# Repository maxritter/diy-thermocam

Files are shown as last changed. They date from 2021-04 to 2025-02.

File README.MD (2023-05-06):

# DIY-Thermocam



The DIY-Thermocam V3 is an open-source thermal imager based on the FLIR Lepton LWIR sensor.

Check out the official website for more information about the project: **[www.diy-thermocam.net](https://www.diy-thermocam.net/)**

**This repository contains:**

- **[Latest firmware releases](https://github.com/maxritter/diy-thermocam/releases)**
- **[Open-source firmware](https://github.com/maxritter/diy-thermocam/tree/master/firmware)**
- **[Desktop software](https://github.com/maxritter/diy-thermocam/tree/master/software)** 
- **[Device enclosure](https://github.com/maxritter/diy-thermocam/tree/master/enclosure)**
- **[Printed circuit board](https://github.com/maxritter/diy-thermocam/tree/master/pcb)**



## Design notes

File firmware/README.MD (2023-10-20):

# DIY-Thermocam - Firmware

### THIS GUIDE IS ONLY REQUIRED, IF YOU WANT TO MAKE CHANGES TO THE FIRMWARE ON YOUR OWN

In case you want to flash the newest version of the firmware to your device without modification, **go to the release section of this repo**.

This guide should work on **all common operating systems** (**Windows, Linux & macOS**).

You need to have [VS Code](https://code.visualstudio.com/) with the [PlatformIO extension](https://platformio.org/install/ide?install=vscode) installed and download the zip archive of this repository. Then **unpack the 3.0 folder inside the firmware subfolder**, **start VS Code** and open this folder  with **File -> Open Folder**. 

**PlatformIO should initialize itself automatically** and you see the buttons to **Build, Upload and Clean** the project in the blue bar **at the bottom**. If this is not the case, **set it up manually using the instructions provided [here](https://platformio.org/install/ide?install=vscode)**.

**Before you click "Upload"**, make sure the Thermocam is **connected to the PC** via a micro USB cable and **turned on**. The **Teensy CLI** should then automatically detect it and **flash the .hex file to the board**. After a restart the changes should be present on the device.

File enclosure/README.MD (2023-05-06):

# DIY-Thermocam - Enclosure

The enclosure has been designed with Google Sketchup in 3D and converted to 2D files to laser-cut them. The 2D SVG file can be opened with Inkscape.

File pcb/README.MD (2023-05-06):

# DIY-Thermocam - PCB

## General

The printed circuit board has been created with [Autosoft Eagle](http://www.autodesk.com/education/free-software/eagle).
Use this software to open the [schematic](3.0/pcb.sch) or [board](3.0/pcb.brd) file.

You can also use the [Gerber.zip](3.0/gerber.zip) and upload it to any PCB service of your choice to manufacture the board, for example [Smart Prototyping](http://www.smart-prototyping.com/PCB-Prototyping.html). 

The PCB dimensions are 89.4mm (w) x 68.4mm (h), 1.6mm thickness and 2 layers.

## Front

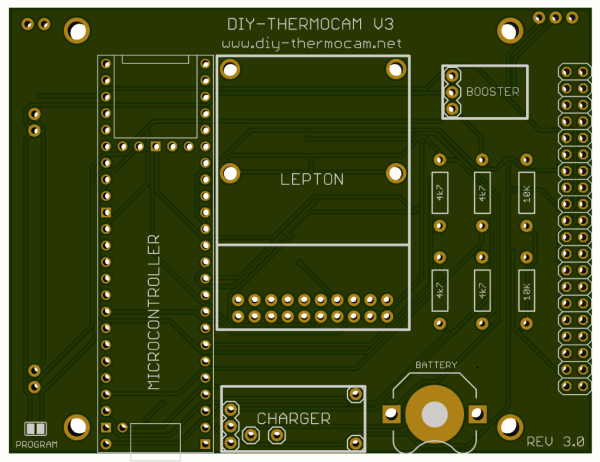
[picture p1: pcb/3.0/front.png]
Front


## Back

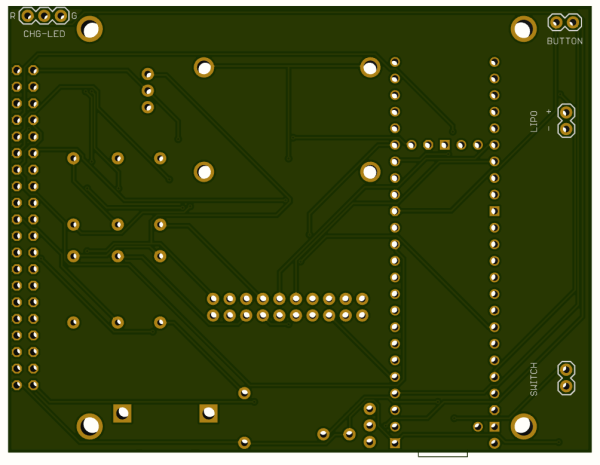
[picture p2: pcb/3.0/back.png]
FRONT


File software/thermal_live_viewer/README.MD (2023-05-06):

# DIY-Thermocam - Thermal Live Viewer

This Python application allows you to connect to your DIY-Thermocam from a PC over the USB serial protocol and stream live thermal images. Run the main.py and change the comport for the device to work.

The Video Recording relies on FFMPEG and does currently only work under Windows.

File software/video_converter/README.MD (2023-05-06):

# DIY-Thermocam - Video Converter

This video converter allows you to convert a whole folder containing bitmap frames from a video or timelapse capture into a movie file.

You can either convert the raw data files to bitmaps on the device, or use the thermal data viewer together with the batch export function to do so (faster).

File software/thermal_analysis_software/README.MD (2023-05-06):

# DIY-Thermocam - Thermal Analysis Software

The thermal analysis software called ThermoVision is created by Joe-C.  The latest stable version that works well with the DIY-Thermocam is 1.7.0.0.

Use the Sample.DAT file in this folder to try out the functionalities of the software. Just drag it into the Main IR window to load it.

For more information and the changelog, check out the [authors website](https://translate.google.com/translate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).

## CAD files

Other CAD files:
enclosure/3.0/enclosure.skp

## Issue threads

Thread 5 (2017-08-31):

choice of microcontroller

haraldg, 2017-08-31:
Hi,

this is a great project and I'm very likely to build a DIY-Thermocam myself.

However, I find it somewhat unfortunate, that the design is based around the TEENSY 3.6 instead of the
[iMX233-OLinuXino-NANO](https://www.olimex.com/Products/OLinuXino/iMX233/iMX233-OLinuXino-NANO/open-source-hardware) which is cheaper, OSHW, industrial grade and already has many of the features on the board that DIY-Thermocam needs extra components for. Though admittedly getting things like the on board battery charger to work might require a non-trivial effort.

Anyway this issue is an attempt to find like-minded people who might join forces to adapt the design to the OLinuXino-NANO or solicit input on why this would be a bad idea.

maxritter, 2017-09-12:
The mentioned single board controller from Olimex is using Linux, whereas the Teensy 3.6 is a bare metal microcontroller. Of course you could also implement the Thermocam on a board running an operating system, like the Raspberry Pi Zero for example, but I decided to implement this project in bare metal C++ on an ARM Cortex M board.

haraldg, 2017-09-14:
The imx233 controller can definitely be programmed in bare metal C++, though maybe some libraries available for the Teensy might be missing. However having a full operating system available is actually the second reason why a Thermocam based on an olinuxino board would appeal to me.

I'm waiting for my order to arraive. After assembling and testing my own Thermocam I will decide how much effort I'm willing to put into a redesign. Of course any input anymone might have is still greatly appreciated.

haraldg, 2017-09-23:
As I'm still looking for people interested in porting the DIY-Thermocam to a OSHW single board computer, I'd appreciate if this issue could remain open to give it some visibility. Is there any reason to close it?

Nprod, 2019-02-01:
It's probably not what you have in mind, but it is possible to use just the FLIR Lepton breakout board directly on any Raspberry pi using the GPIO pins. If the olinuxino, or any other single-board computer of choice has I2C and SPI pins in its GPIO board, you should be able to get a Lepton running. I've successfully gotten it to run on a chinese Orange PI, the main downside being that it's running a full operating system so the whole setup isn't portable.

Max's diy-thermocam is more expensive and more complicated to setup by comparison, but it has one big advantage that it's all integrated into a single unit. And when you're taking thermal images chances are you'll be out and about.

maxritter, 2019-02-01:
That's true :) There are various other projects and tutorial using a more advanced SOPC like the Raspberry for directly controlling and displaying the thermal image from the Lepton.

I think as you said, it depends on your use case and of course also the budget.

haraldg, 2019-02-02:
Yes. However I specifically suggested the olinuxino, because I believe such a setup would be as portable and the PCB interfacing the main board and the lepton would be almost trivial. (Ie making it easier to optimize for themal constraints, etc.)

The big part of such a project would be writing the firmware (probably mostly from scratch) as a linux application. My current estimate is, that developing a ThermocamV3 based on the olinuxino or other SBC would take me about 1-2 month full time work. - For something, that works. Doing it properly, ie. submitting drivers upstream to the mainline kernel, etc. would take even longer.

Unfortunately I don't have that much free time these days. Also the ThermocamV2 works too well for me, to put that much effort into something that would be slightly cheaper, a bit more flexible and OSHW.

However if somebody else is taking the initiative, I'd still be happy to help out with my skills. (Mostly kernel and embedded linux related.)

Nprod, 2019-02-02:
I don't know, sounds like a lot of work for something that's just 4€ cheaper. Maybe the added CPU power would make the image refresh rate quicker, but that's already limited to 9hz in the lepton itself...

Closed 2021-03-10.

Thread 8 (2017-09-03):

Calibrating problems

alexandreamato, 2017-09-03:
Hi,
I just built my own DIY-Thermocam. Congratulations on the project! If I were more careful I would have taken some photos of the built process to share with you and here. I really like the [thermography and made some attempts before](https://www.youtube.com/watch?v=XctIPPcHPTE&feature=youtu.be).
Anyway. I know it is working, at least a part of it, because I can start the calibration process, and I can move the arrows to put thermo image over photo image. But after that, calibrations asks to point to different heat objects slowly, but my calibration process never changes, stays at 0%.
Also, I had to upload firmware version 2.40. I don't know why when uploading newer versions it says my teensy is not compatible.
One hint for everyone, I use Windows 10, and there was no way to upload firmware in COM10, but it was very easy with https://github.com/Koromix/tytools
Do anyone have any idea how to pass or bypass this calibration?
Thanks

nielsswinkels, 2017-09-04:
Did you see the Firmware update manual? In there at step 5 there is a link to how to change the comport on windows to com 10: http://plugable.com/2011/07/04/how-to-change-the-com-port-for-a-usb-serial-adapter-on-windows-7/

nielsswinkels, 2017-09-04:
Which teensy are you using?
And are you using the firmware updater?

alexandreamato, 2017-09-08:
I believe it is a 3.6 Teensy, my order says: 1568-1442-ND 32.50000 32.50, TEENSY 3.6, HTSUS: 8471.50.0150 ECCN: 3A991A2, LEAD: LEAD NA ROHS: ROHS NA, COUNTRY/ORIGIN: USA
I didn't use the firmware updater because tytools managed to update at least the 2.40 version without changing to COM10. Do you believe it is necessary? I will do it tomorrow!
Also, regarding calibration, can you imagine why I cannot progress? it stays in 0%?
I only had problems soldering the 2 smallest pins in the SD card, they were very difficult. But I believe they are not the most important ones?! Or am I wrong?

alexandreamato, 2017-09-09:
I did it, using the upgrade app and the com10 port I managed to upgrade to the latest firmware.
My only problem now is calibrating. It stays calibrating forever.
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

nielsswinkels, 2017-09-09:
I have to admit i don't know much, except that i recently put together one of these.

I wonder if it could be an issue with the big cylindrical sensor? If i understand it correctly that is used to know actual temperature values from the values the heatcamera sensor says. Could you double check that is mounted correctly?

As for your photo, i can't see if the solder point is ok, it is to blurry for me. But you could always try to resolder it if you don't trust it?

alexandreamato, 2017-09-12:
I rechecked the big cylindrical sensor, it is positioned correctedly and soldered ok. Is it very fragile? Can it be broken? Do you have any idea how to test it?
Resoldering the location of the photo would be very difficult because of the location. But it is the SD card, so I studied the code, to see what happened when it stopped working. It doesn't yet access the SD card, so it is not the problem.
It seems it stops here:

`//If the temperature changes too much, do not take that measurement
//Get 100 different calibration samples
		while (counter < 100) {
			//Store time elapsed
			long timeElapsed = millis();

			//Repeat measurement as long as there is no new average
			do {
				//Safe delay for bad PCB routing
				delay(10);
				//Get temperatures
				lepton_getRawValues();
				//Calculate the average
				average = calcAverage();
			} while ((average == average_old) || (average == 0));

			//Store old average
			average_old = average;

			//Measure new value from MLX90614
			temp = mlx90614_getTemp();

			//If the temperature changes too much, do not take that measurement
if (abs(temp - temp_old) < 10) {
				//Store values
				calLepton[counter] = average;
				calMLX90614[counter] = temp;

				//Find minimum and maximum value
				if (average > maxValue)
					maxValue = average;
				if (average < minValue)
					minValue = average;

				//Refresh status on screen in steps of 10, not for serial
				if (((counter % 10) == 0) && !serial) {
					char buffer[20];
					sprintf(buffer, "Status: %2d%%", counter);
// It arrives here at least once
					display_print(buffer, CENTER, 140);
				}

				//When doing this in serial mode, print counter
				if (serial)
					Serial.write(counter);

				//Raise counter
				counter++;
			}

			//Store old spot temperature
			temp_old = temp;

			//Wait at least 111ms between two measurements (9Hz)
			while ((millis() - timeElapsed) < 111);

			//If the user wants to abort and is not in first start or serial mode
			if (touch_touched() && !firstStart && !serial) {
				int pressedButton = buttons_checkButtons(true);
				//Abort
				if (pressedButton == 0)
					return;
			}
`
As "Status" remains at 0%, I imagine something is happening in this loop. I wanted to try the serial output, but the "FirstStart" routine runs the "calibrationProcess" with serial as false. I am really lost here.

maxritter, 2017-09-12:
Hey there,

sorry for my late reply, I was on vacation.

As the combined alignment screen is working, the FLIR Lepton sensor and visual camera are doing fine. The calibration screen utilizes the MLX90614 spot sensor for the first time.

Two things can go wrong here:
- You use the wrong version of the MLX90614. Only the BCF version is supported for the DIY-Thermocam V2
- You soldered the sensor in the wrong position. Check step 10 of the assembly guide and make sure the little indicator matches the mark on the PCB

Also check if there is a 3.3V voltage between VCC and GND of the MLX90614 and that SDA is connected to Teensy pin 18 and SCL to Teensy pin 19, with no connections to other pins. The datasheet contains the pin locations: https://github.com/maxritter/DIY-Thermocam/blob/master/Datasheets/MLX90614.pdf

Please tell me if that solved your problem.

Wishes,
Max

alexandreamato, 2017-09-12:
Hi Max, it is an honor to talk to you. Congratulations on your project. It is very interesting!!
I tried all the suggestions:
I believe the version is right, I bought it directly from the link in github, If starts with BCF, but the number following is 9696A. I attached a photo
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
The position is right:
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
Voltage OK
pin 18 and pin 19 seems ok. But I noticed is connected to other pins by the board.
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
the only piece I had to substitute was a missing 4.7k resistor that didn't came in the kit. I used a bigger one, but with the same resistance.

maxritter, 2017-09-13:
Thank you very much for your compliment :)

From the pictures, everything looks solid! The spot sensor is also the right version.

So for the hardware side, I can only recommend you to resolder all pins and check if there are no hidden solder bridges, sometimes they are very small. Also check that the Lepton sensor is inserted tightly into the socket.

For the software side, you can try to reset the EEPROM so the spot sensor is flashed once again. Upload this sketch with the Teensy Loader, then reflash firmware 2.43: https://www.dropbox.com/s/jqcwolz5vajj0u5/eeprom_clear.ino.hex?dl=1

When in calibration mode, you have to move the device around to different temperatures, otherwise it will not make any progress. But a moving hand in front of the sensor should be enough to let it progress.

In case all that does not help, you can try to skip the calibration and directly proceed to live mode. Flash this sketch, I commented out the calibration part here: https://www.dropbox.com/s/jtglat0sg5msu17/NoCalibration.hex?dl=1
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
alexandreamato, 2017-09-13:
I need to go back to my lab to do that. Probably later today! Thanks

alexandreamato, 2017-09-14:
Here is the output:
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

maxritter, 2017-09-15:
Okay, so it got stuck in a while loop..

Please try that firmware file: https://www.dropbox.com/s/e6encj2gxblkum0/Firmware_V2_FixCalib.hex?dl=1

alexandreamato, 2017-09-16:
here it is. "Bad Calibration", but doesn't halt
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

maxritter, 2017-09-18:
Alright, so let's see what temperatures and raw values the device measures during calibration..

Please flash this file: https://www.dropbox.com/s/zqa7e7krh5r6io8/Firmware_V2_CalibOut.hex?dl=1

And send me the debug output as .txt / .csv file.
It prints three lines for each of the 100 measurements. First is id, second Lepton raw value and third MLX90614 absolute temperature. Either the raw value or abs. temp. must be wrong.

alexandreamato, 2017-09-21:
Hi, I had some trouble to upload the new firmware, but here it is:

7723
26.34
93
7723
26.14
94
7723
26.36
95
7723
26.36
96
7723
26.34
97
7723
26.34
98
7723
26.10
99
7723
26.36

alexandreamato, 2017-09-22:
a full one:

0
8149
36.88
1
8149
36.64
2
8149
36.76
3
8149
36.78
4
8149
36.36
5
8149
36.86
6
8149
36.94
7
8149
36.78
8
8149
36.60
9
8149
37.12
10
8149
37.12
11
8149
36.94
12
8149
36.94
13
8149
35.58
14
8149
37.60
15
8149
37.34
16
8149
37.24
17
8149
37.28
18
8149
37.60
19
8149
37.26
20
8149
37.26
21
8149
36.94
22
8149
36.94
23
8149
36.94
24
8149
36.60
25
8149
36.60
26
8149
37.02
27
8149
36.60
28
8149
36.62
29
8149
36.80
30
8149
36.84
31
8149
37.08
32
8149
36.72
33
8149
36.72
34
8149
36.60
35
8149
36.60
36
8149
37.10
37
8149
36.54
38
8149
36.44
39
8149
36.84
40
8149
36.54
41
8149
37.02
42
8149
36.86
43
8149
36.70
44
8149
36.54
45
8149
36.54
46
8149
36.68
47
8149
36.68
48
8149
36.78
49
8149
36.92
50
8149
36.92
51
8149
36.72
52
8149
34.98
53
8149
34.98
54
8149
28.16
55
8149
26.40
56
8149
26.76
57
8149
26.96
58
8149
26.90
59
8149
26.40
60
8149
27.84
61
8149
27.84
62
8149
27.14
63
8149
27.14
64
8149
27.52
65
8149
27.46
66
8149
27.66
67
8149
27.60
68
8149
27.14
69
8149
26.98
70
8149
27.42
71
8149
27.40
72
8149
26.66
73
8149
26.66
74
8149
36.30
75
8149
36.30
76
8149
35.36
77
8149
32.82
78
8149
32.82
79
8149
33.02
80
8149
34.42
81
8149
34.60
82
8149
35.14
83
8149
34.12
84
8149
34.60
85
8149
34.80
86
8149
34.80
87
8149
35.00
88
8149
35.00
89
8149
34.24
90
8149
34.42
91
8149
34.38
92
8149
34.54
93
8149
34.42
94
8149
34.58
95
8149
34.60
96
8149
34.60
97
8149
35.04
98
8149
35.04
99
8149
35.04

alexandreamato, 2017-09-22:
It seems Lepton raw value is wrong, not MLX90614 absolute temperature ??

maxritter, 2017-09-23:
Yes, it seems it is the Lepton in that case, because the raw value is always the same..

Please try that firmware: https://www.dropbox.com/s/fk6m2h6x4j9jcev/Firmware_V2_2.44B2.hex?dl=1
It has no debug outprints included any more, just see if you can get a decent calibration there.

nielsswinkels, 2017-09-23:
OK, let me get back to you

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

alexandreamato, 2017-09-23:
Did not work, See this video
https://vimeo.com/235138684/cab1ef6a1e

Maybe my lepton is different from yours? This was the only piece I already had from another project.
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

maxritter, 2017-09-26:
Yeah, I'm using the shuttered version of the Lepton for my projects here..
But it SHOULD work with the non-shuttered too.. Maybe the error is somewhere there, please try that approach: https://www.dropbox.com/s/0z0u3ikag7ykpz2/Firmware_V2_2.44B3.hex?dl=1
It removes the call to the Lepton shutter. On startup, there will be a model ID printed to the serial console, please send me that number as well.

alexandreamato, 2017-09-28:
Hi Max, I am out of town, as soon as I am back I will test.

alexandreamato, 2017-10-14:
Sorry for my delay. It seems to be working now.
At least the calibration finished without error.
This is the model ID in serial: 05-060340-

maxritter, 2017-10-15:
Thanks for your help!

I released firmware 2.44, that includes this bugfix: https://github.com/maxritter/DIY-Thermocam/tree/master/Firmware/Releases/2.44

alexandreamato, 2017-10-15:
Thanks a lot!
May I ask what is your final opinion about my problem?
What caused it?

maxritter, 2017-10-16:
The calibration method missdetected the Lepton2 non-shuttered as a Lepton2 shuttered.
At the beginning of the process, it tried to run a shutter command, which caused the raw sensor values to freeze afterwards.

Closed 2017-10-24.

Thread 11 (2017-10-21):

Data doesn't get transfered to PC

JustaCopy, 2017-10-21:
Hi,

i can connect my DIY-Thermocam (TC) with ThermalDataView and ThermoVision, but the programs don't recieve any data from the device. (No captured images, no live-stream)

I can charge the TC and update the firmware. Do you have any suggestion where i should start looking for?

maxritter, 2017-10-21:
What operating system are you using? For Windows, you can download the serial driver here: https://www.pjrc.com/teensy/serial_install.exe , for Linux here: https://www.pjrc.com/teensy/49-teensy.rules
Have you updated your device to the newest firmware 2.44?
Have you changed the comport to COM10?
Is there an error message when you try to f.ex. use the ThermalLiveViewer?

JustaCopy, 2017-10-22:
Thanks for the fast reply.
I use Windows 10. Driver you describe is installed.
Yes, i use the newest firmware 2.44
Yes, i tried to change the comport to COM 10.
ThermoVision gives the error "DIY_noDataRecievedRestarts==5->Stream OFF"
Now i tried ThermalLiveViewer. There i can see the thermal image. So, no error there.

maxritter, 2017-10-22:
For issues concerning the ThermoVision SW, please contact the author directly with the given error message: joe-c-henkel@web.de

JustaCopy, 2017-10-23:
I'll ask him by chance. Your ThermalLiveViewer works pretty well, i guess i'll stick with it for now.
One last question, is it intended, that windows doesn't see the SD-Card?

maxritter, 2017-10-24:
The DIY-Thermocam V2 unfortunately does not support mass storage mounting for the SD card. This has to do with the internal wiring of the SD SPI bus. So the only solution is to use an external card reader.

Closed 2017-10-24.

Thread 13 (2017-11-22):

battery size doesn't fit

haraldg, 2017-11-22:
Hi,

finally got my DIY-Thermocam kit from groupgets. There are some minor annoyances, like I got two tripods but miss some other parts and the import tax was way havier then expected. However the real issue is not their fault: The battery doesn't fit between the display connector and the push button!

I just checked. They sent me this battery: https://www.sparkfun.com/products/13855, which is actually linked from the DIY-Thermocam readme. However this battery has the following dimensions: 5.6mm x 49.2mm x 68.8mm, while the README states the following max. dimens.: 60mm (w) x 55mm (l) x 6.5mm (h)

I think the link in the README should be removed and maybe groupgets notified, that they need to update their kit.

maxritter, 2017-11-22:
Hey,

thanks for your feedback and sorry for the inconvenience.

Can you please post an image showing the battery in place? I suspect the length of the sparkfun battery is too high?

Wishes,
Max

haraldg, 2017-11-23:
Sorry, can't take a photo at the moment. Yes, the problem is the dimension of 68.8mm of the sparkfun battery. 60mm is the maximum - as is actually stated in the README correctly.

maxritter, 2017-11-23:
Thanks for the observation.

I have to deeply apologize for this mistake. I added this new battery type and didn't check the specifications carefully enough.

It is fixed now on the website and I also forwarded this to GroupGets. I hope not too many users are affected by it.

Concerning your particular case, please also get in touch with GroupGets, as I do not have any replacement parts for the battery here.

haraldg, 2017-11-24:
Don't feel to bad about this. Such mistakes are bound to happen and in the grand scheme of things buying a second battery is only a minor annoyance. Actually I'm very happy to have a thermal imager where I can improve the firmware whenever needed and it will cost me only twice the prize of a cheap commercial solution in the end.

For now I taped the too large battery to the exterior of the case and ran some first tests. I guess I should open new tickets for the issues I find. However some of the things I want to discuss are really just related to how to do high quality measurements - information that would be interesting to many users I guess. If there was some kind of forum, where such posts would stay easily accessible, that would be very useful IMO.

Anyway, closing this issue now.

Closed 2017-11-24.

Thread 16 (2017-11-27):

poor calibration performance

haraldg, 2017-11-27:
Hi,

the automatic calibration procedure is quite nice - at least it is much simpler than any manual calibration would be. However results are somewhat underwhelming: Most of the time my DIY-thermocam shows temperatures about 3-6K too low. I think the problem mainly comes from the spot sensor: It shows quite reasonable values around room temperature, but at colder temperatures the values become quite too low: For example today the temperature outside was clearly above 0°C (air and any surfaced I can think of), but the spot sensor showed temperatures around -8°C.

Is there any way to recalibrate the spot sensor itself, to see if this yields better calibration of thermal images too?

Im also thinking about just taking raw data with the thermocam and do any calibration and analysis on the PC later. But this is made more difficult by #15.

haraldg, 2017-12-14:
I have written a short article about thermocam calibration:

https://github.com/haraldg/thermocam-tools/blob/master/manual-calibration.md

maxritter, 2017-12-14:
Thanks for this nice article! I added it to the documents so other users can better find it, hope this is okay for you :)

haraldg, 2017-12-14:
Of course it is okay for me. It was written for the benefit of other people after all ...

However I might update it to improve my rather poor english and maybe also with additional results in the future. So maybe linking to it would be easier to maintain than including it.

I am rather suprised about the poor spot sensor performance - looks pretty much useless to me. I wonder whether there is some way to improve this on the firmware side.

haraldg, 2018-01-17:
So I looked into the spot sensor (calibration) problem a bit more and it turns out my initial diagnosis was wrong: It is NOT the ambient temperature that matters, but just the uptime of the thermocam: After switching the thermocam on, the spot sensor starts at reasonable values, but then drifts down to lower values.

I guess this is caused by the camera warming up (it gets noticably warm even on the outside after about half an hour of operation). I notice that the used sensor should be resistant to internal temperature gradients to mitigate this very issue. However, unless the sensor I got is broken in some subtle way, it seems the thermal regime inside the thermocam is just too much.

I guess the only real fix for this is to redesign the thermocam with heat distribution in mind. This probably is not going to happen for quite a while, so I'm looking into work arounds.

Solution 1: Disable the spot sensor completely, just using manual calibration. This will need a change to the firmware, I think.

Solution 2: Reduce heat production inside the thermocam. This would probably only reduce the issue with the spot sensor, not mitigate it. OTOH it would help with other things (drift of the lepton, battery life) as well, so might still be worthwhile. I don't know how the components contribute to heat production, but I guess a huge part comes from the microcontroller.

There are a number of ways, how I think the microcontroller could be made more energy efficient.
* make it sleep instead of busy-looping in some places of the code
* reduce the work load - for example I rarely use the optical camera, yet it seems it can't be actually disabled
* reduce the clock speed

I guess all these ideas require modifying the firmware. So my first task is to look into how it can be compiled on linux. Any help with that or with the issue in general would be very appreciated - I'm new to arduino, so will need a while to get up to speed.

maxritter, 2018-01-18:
Thanks for this further investigation.

I already assumed something like this, as I also made kind of the same observations. The internal heatup seems to be too much, so that the MLX90614 can not compensate for it.

Maybe it's possible to find some compensation formula for this self-heating. If I know what exactly to implement in the firmware, I can easily do that :)

haraldg, 2018-01-20:
About compensation: The spot sensor drift is surprisingly repeatable. Even if I change parameters like adding/removing the battery (should be a huge heat buffer), the curve (drift over time) stays pretty much the same in my tests. However, I think a time-based compensation won't work, because I have to reboot the camera when I'm hit by #14.

However there are at least two internal temperature sensors available: The internal temperature on the MLX90614 and the die-temperature of the MK66. Maybe something can be done with either of those...

Also it seems that the drift of the spot sensor is pretty much synchronized with the drift of the lepton sensor itself. On one hand this makes the spot sensor pretty much a no-op, on the other hand experimenting with the built-in temperature compensation of the lepton becomes much more interesting. (I believe it is disabled by default on the non-radiometric versions, but the feature is there.) To that end I'd like to experiment with register settings on the lepton. To make this feasable, the lepton CCI would need to be forwarded via the thermocam serial interface.

About the warmup itself: As I have only one thermocam, I can't take a thermal image of the thermocam itself. However I found the following forum post / image: https://forum.pjrc.com/threads/45012-how-warm-the-teensy-3-6-gets?p=146777&viewfull=1#post146777

Looks to me, like the main heat comes from the µC and two rather inefficient regulators. I guess all the power for the lepton and the display also comes from these regulators, so they might be really hot in the thermocam. I still intend to experiment with lower clock speeds (to simulate the effect of more efficient code), but I suspect the teensy 3.6 might not have been a good choice for such a project - at least not without adding external regulators.

wiiverueckt, 2018-03-26:
Is it possible to port the code to rapberry pi zero?
The CPU is much faster and also the price is much lower.
I think its also programmable in arduino if you want.
Maybe even the videoout could be implemented.
Does the drift stop after a while or is it drifting all the time?

haraldg, 2018-03-28:
Hi @wiiverueckt,

regarding using other CPUs there is issue #5 - I'm still interested in this.

The drift is high at the beginning and reduces over time as the camera approaches thermal equillibrium. However this takes rather long, probably the battery is depleted at the same time. I usually use the thermocam for about an hour in a row and this is not enough.

Actually the lepton sensors have a mode (not used by the thermocam firmware ATM) where the sensor tries to compensate for changes in sensor temperature. It is on my todo-list to experiment with this mode - could be that in this mode the lepton alone can produce better results than the calibration sensor. Unfortunately I have little time to work on this.

blotske, 2018-04-03:
@wiiverueckt it would be harder (not impossible) to do without a realtime processor.  That is why its very common for a realtime microcontroller to be attached directly to the sensor/device and that connected to a higher level OS and processor.

haraldg, 2018-04-18:
Ah, sorry I forgot to report some of my on results in this issue: I compiled my own build of the firmware some time ago at 120 MHz clock speed IIRC. The result was a mixed bag: The drift is slower at lower clock speed, so it kind of confirms our theory. But it is still strong enough to make the spot sensor quite useless, so I didn't run enough tests to get a detailed comparison. I suspect at 120MHz the main heat source actually is the regulators supplying the display with power, but since displayless mode is not useful for me, I did not experiments to check this theory.

Instead I'm meaning to look into the temperature compensation abilities of the lepton itself. However this requires some significant changes to the firmware, maybe adding some kind of debug mode to make experimenting with lepton settings easier. I don't have time to work on such a project in the near future, so I can only encourage you and others to look into this and offer to help from the sidelines.

Closed 2021-03-10.

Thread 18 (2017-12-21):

USB connection stuck at "lepton_getRawValues()" function

reanovich, 2017-12-21:
I only have Teensy 3.6 and Lepton 2 (shutter) at the moment and connect them with cables. Every time I try to run the firmware, it will always stuck at  "lepton_getRawValues()". This problem occurs because teensy never got 60 lines from lepton. It always loop at line 0 because the error value is count up to 255. I have tried with 2 pcs Lepton 2 (shutter) and 1 Lepton 2(non shutter) and the problem still exist. This is how I connect teensy with lepton :

- pin 11 to MOSI
- pin 12 to MISO
- pin 14 to CLK
- pin 15 to CS
- pin 18 to SDA
- pin 19 to SCL

I powered them from USB so I connect this two pin
- pin GND (Teensy) to GND (Lepton)
- pin Vin (Teensy) to Vin (Lepton)

I already test the Lepton module with my own code to read the package (using SPI and SPI1) and I can get number 0 - 60 from the first two bytes (ID bytes). So there should be no problem with my Lepton module.

Any idea why this happens?

maxritter, 2017-12-21:
Can you post the full code you are using to test this setup?

If you connect CLK to pin 14, you also need to issue startAltClockline() in addition to SPI.beginTransaction(SPISettings(20000000, MSBFIRST, SPI_MODE1)) and digitalWrite(pin_lepton_cs, LOW) to begin a transaction with the Lepton2.

What is the LeptonReadError retVal, when you try to read a package?

reanovich, 2017-12-22:
Hi Max, I'm using this code to test my Lepton module
<details><summary>I'm gonna use this fancy spoiler because the code is too long</summary><p>

```Arduino
#include "Wire.h"
#include "SPI.h"

#define USE_SPI1
/* Wiring
- SPI1
	-- CS	pin 6
	-- MOSI	pin 21
	-- MISO	pin 5
	-- SCK	pin 20
- SPI
	-- CS	pin 10
	-- MOSI	pin 11
	-- MISO	pin 12
	-- SCK	pin 13
*/

#ifdef USE_SPI1
#define pin_lepton_cs 6
#define pin_lepton_mosi (21)
#define pin_lepton_miso (5)
#define pin_lepton_sck  (20)
#else
#define pin_lepton_cs   (10)
#endif

void setup() {
	// put your setup code here, to run once:
	Wire.begin();
	Serial.begin(115200);

	Serial.println("Lepton module test");

#ifdef USE_SPI1
	// Initiate lepton SPI
	Serial.println("Init SPI1");
	pinMode(pin_lepton_cs, OUTPUT);
	digitalWriteFast(pin_lepton_cs, HIGH);
	SPI1.setMISO(pin_lepton_miso);
	SPI1.setMOSI(pin_lepton_mosi);
	SPI1.setSCK(pin_lepton_sck);
	SPI1.begin();
#else
	// Initiate lepton SPI
	Serial.println("Init SPI");
	pinMode(pin_lepton_cs, OUTPUT);
	digitalWriteFast(pin_lepton_cs, HIGH);
	SPI.begin();
#endif
}

void loop() {
	// put your main code here, to run repeatedly:
	int line = 0;
	byte leptonFrame[164];
	byte imageFrame[60 * 164];
	while (line != 60)
	{
#ifdef USE_SPI1
		// Start transaction
		SPI1.beginTransaction(SPISettings(20000000, MSBFIRST, SPI_MODE1));

		// Initiate CS pin
		digitalWriteFast(pin_lepton_cs, LOW);

		// Receive one frame over SPI
		for (int i = 0; i < (164 / 2); i++){
			// Read value via SPI
			leptonFrame[2 * i] = SPI1.transfer(0x00);
			leptonFrame[2 * i + 1] = SPI1.transfer(0x00);
		}

		// Disable CS pin
		digitalWriteFast(pin_lepton_cs, HIGH);

		// Stop transaction
		SPI1.endTransaction();
#else
		// Start transaction
		SPI.beginTransaction(SPISettings(20000000, MSBFIRST, SPI_MODE1));

		// Initiate CS pin
		digitalWriteFast(pin_lepton_cs, LOW);

		// Receive one frame over SPI
		for (int i = 0; i < (164 / 2); i++){
			// Read value via SPI
			leptonFrame[2 * i] = SPI.transfer(0x00);
			leptonFrame[2 * i + 1] = SPI.transfer(0x00);
		}

		// Disable CS pin
		digitalWriteFast(pin_lepton_cs, HIGH);

		// Stop transaction
		SPI.endTransaction();
#endif

		if ((leptonFrame[0] & 0x0F) != 0x0F){
			if (leptonFrame[1] == line){
				for (int i = 0; i < 164; i++){
					// Save frame
					imageFrame[(line * 164) + i] = leptonFrame[i];
				}
				line++;
			}
		}
	}

	// Print lepton frame ID
	for (size_t i = 0; i < 60; i++)
	{
		Serial.printf("%02X\t", imageFrame[(164 * i) + 1]);
		if (i % 10 == 9)
		{
			Serial.println();
		}
	}
	Serial.println();

	while (1);
}
```

</p></details>

The output should be like this
```
Lepton module test
Init SPI1
00	01	02	03	04	05	06	07	08	09
0A	0B	0C	0D	0E	0F	10	11	12	13
14	15	16	17	18	19	1A	1B	1C	1D
1E	1F	20	21	22	23	24	25	26	27
28	29	2A	2B	2C	2D	2E	2F	30	31
32	33	34	35	36	37	38	39	3A	3B
```

Somehow when I tried my code with CS at pin 15 and SCK at pin 14, it just hung up and never print any result (after init SPI) so I failed to replicate the same connection as DIY-Thermocam to make the lepton work.

the retVal value are 0,1, and sometimes 3

maxritter, 2018-04-17:
I am closing this issue now, as it's not directly related to the DIY-Thermocam.

Closed 2018-04-17.

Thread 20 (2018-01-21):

compiling the firmware

haraldg, 2018-01-21:
I'm trying to compile the firmware myself, but I have some trouble understanding how things should fit together.

I got the Arduino IDE (1.8.5) and Teensyduino (1.41) installed, which was quite non-trivial as I'm on arm64 but only 32-bit arm binaries are provided. Anyway, it seems to work now.

But getting Visual Studio as is suggested in your README for arm64 linux seems not viable. So I tried building the firmware directly from Arduino IDE. After renaming the Folder "Source" into "DIY-Thermocam" I could open the sketch and the compile phase was successful. However the linker produced lots of errors about unresolved symbols.

Basically the problem seems to be, that the "external libraries" aren't actually external, but are copied into the source tree. The compiler finds and includes all header files, so there is no problem. However the *.cpp files of the libraries never get compiled, so the linker has nothing to link actually.

A few questions:
1) Before I start messing with things: Do you have any recommendation on how to compile your code without Visual Studio?
2) Since I guess it would be the most straight forward solution: Why are the external libraries copied into the project? Would I run into any trouble, if I just switched back to using the official libraries? Would such a change be acceptable for you upstream?
3) I guess, I could write a Makefile for the libraries. But how would I then use this "manually" compiled library to build the sketch?

haraldg, 2018-02-01:
Meanwhile I successfully compiled the Firmware on arm64 linux with the arduino IDE only.

Basically the following steps where necessary:

* Add symlinks from $(HOME)/Arduino/libraries, to the external libraries that can't be installed from the IDE. These are ADC, I2C and Metro.
* Install all the other used libraries from within the IDE.
* Move tjpgd.c and tjpgd.h into their own folder in the external libraries directory and add a symlink for that as well.
* Probably optional: Comment (or remove) the #include directives for the external libraries in the main sketch file and replace them with proper #include directives for system libraries.
* Symlink (or copy) the remaining *.cpp and *.c files the the toplevel source directory, so Arduino IDE sees them. Also include the referenced *.h files - not many! Maybe the best way for this would be to just move these files into their own DiyThermocamHelpers "external" library.

That's it. Not all the difficult after all.

I guess it would make sense to provide a pull request for some of these changes, to keep differences between my branches and the master branch to a minimum. Which of these changes would be acceptable to you? Also I won't be able to test compilation on Windows / with Visual Studio and I can't update proprietary Visual Studio files, if I move some source files around. I'd need you cooperation on that part.

What do you think?

maxritter, 2018-04-17:
I will provide an extra repo for the firmware soon, that includes a refactored version of the source code as well as a tutorial that will be based on Eclipse. This way it can be also used on other operating systems ;)

maxritter, 2018-04-17:
The updated firmware repo is now online!

haraldg, 2018-04-18:
Thanks, that looks very promising! Having an extra repository for just the firmware does make my life a lot easier. I hopefully have time to test this (and the debounce improvement) on the weekend.

I think in the long run it might be useful to have a way of fully automatic building the firmware for continous integration testing. Not much of a concern now, but once people start to contribute lots of pull requests, this would be nice to have.

haraldg, 2018-04-21:
Compiling the new firmware on linux fails because of case sensitive filenames! I can prepare a PR, but do you want all filenames lower case (like they are used in the code) or should the code be changed to mixed case filenames?

maxritter, 2018-04-22:
Thanks for the info. I changed all module filenames to lowercase now.

haraldg, 2018-05-04:
Thanks, I successfully compiled the firmware now on linux / arm64. I still used a Arduino IDE only approach (ie without eclipse), but no changes to the source files where necessary this time (only renaming main.cpp to src.ino) so I can now easily keep track of firmware updates without having to merge local changes anymore.

I haven't tried it yet, but I expect it will be easy now to setup automatic building with arduino-builder from the command line. As far as I'm concerned, this issue can be closed now.

Thanks!

Closed 2018-05-06.

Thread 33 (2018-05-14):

Cannot connect to camera as a mass storage device after firmware update

jesass, 2018-05-14:
I have a version 1 DIY Thermocam that I have been using that has been running version 1.25 firmware.  All functions supported by the 1.25 firmware worked as expected including mounting the camera as a mass storage device to transfer images to a P.C.

After I upgraded the firmware to version 2.46, I cannot mount the camera as a mass storage device.  If I go into the camera menu and select the USB File Transfer icon and then select the YES button, the camera briefly displays the "Disconnect USB cable to return"  message and then the camera reboots.

Is mounting the camera as a mass storage device supported in the 2.46 firmware for version 1 hardware?

System Info:
DIY Thermocam version 1 hardware flashed from version 1.25 firmware to version 2.46 firmware
Windows 10
Camera connected on COM5

maxritter, 2018-05-16:
Yes, the newest firmware should also support mass storage mode on the DIY-Thermocam V1. But I have to admit I didn't test it in version 2.46. Can you flash 2.45 or a prior version and check if it works there?

jesass, 2018-05-16:
Are there old firmwares archived here?  I am having trouble finding any firmware except the current 2.46 version.

maxritter, 2018-06-05:
You can find previous firmware releases here: http://diy-thermocam.bplaced.net/Firmware/

jesass, 2018-06-08:
Thanks for the link to the previous firmwares.  I did some testing with my version 1 camera and saw slightly different results as the firmware progressed from v.1.25 to v.2.46.  The results are below.

From v.1.25 to v.2.39 - Normal operation was observed.  Normal operation is defined as the following:
- The USB icon is pressed from the main menu.
- A message pops up that says "Disconnect USB cable to return" is displayed.
- Windows USB disconnect sound is heard followed by the Windows USB connect sound.
- A drive opens in Windows Explorer displaying the contents of the onboard SD card.  The contents of the drive can be accessed.
- When the USB cable is unplugged, the camera reboots.

Starting with the v.2.40 firmware to the v.2.44 firmware, a slightly different behavior was observed:
- The USB icon is pressed from the main menu.
- A message pops up that says "Disconnect USB cable to return" is displayed.
- Windows USB disconnect sound is heard.
- Nothing happens
- If the USB cable is disconnected and then reconnected,  the Windows USB disconnect sound is heard when the cable is disconnected and then the Windows USB connect sound is heard and then the contents of the SD card is displayed in Windows Explorer.  The contents of the drive can be accessed.  The message "Disconnect USB cable to return" is still displayed on the camera display.
- When the USB cable is unplugged, the camera reboots.

With the v.2.45 firmware, the normal behavior (v.1.25 to v.2.39) was observed.

With the v.2.46 firmware the following behavior was observed:
- The USB icon is pressed from the main menu.
- A message pops up that says "Disconnect USB cable to return" is displayed.
- Windows USB disconnect sound is heard.
- The camera reboots.

I took a look at the change log for 2.45 to 2.46 and did not see anything that would point to the change in behavior between v.2.45 and v.2.46.

I am not asking for a fix to this since I realize that I have an old device and the newer device does not seem to have problems.  I am posting this so that others that may have version 1 camera have a resoure to help solve problems after firmware upgrades.

Thanks again for all your help with this issue.  With v2.45 firmware, I have a functional camera again !

maxritter, 2018-06-17:
Thanks for those detailed observations!

I had a look what could be the issue with 2.46 and the MSD functionality, but didn't find a quick fix.. Hopefully I will have some more time to investigate this soon, and hope you can use 2.45 without any big issues in the meantime :)

jesass, 2018-06-24:
The v.2.45 firmware works fine for what I am doing and it is a vast improvement from the v.1.25 that I was using!

If you are going to do some troubleshooting on this issue, I am willing to test any potential fixes that you come up with.

Closed 2021-03-10.

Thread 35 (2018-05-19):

SD Card not seen

stevefleischer, 2018-05-19:
I am currently building my second Thermocam, the first one was successful, but this time I have hit a problem.
The device boots up and I go through the setup screens without a problem. Unfortunately, the start up process stops with the message "Checking SD card..." and then "Please insert SD card". However, the SD card is inserted into the card reader properly. It is the one I used to test the first camera with and it worked then, I was able to save various thermal images to it.

My questions are:
1) is a faulty card reader connection the only cause of this error (given the card has been tested in another Thermocam)
2) is it possible to bypass the SD card detection part of the boot up process so that I can test the actual FLIR is working? I don't (at the moment) need to save any images.

nacerazel, 2018-05-19:
Hello , i m working on my first thermocam, my touchscreen doesn t work, please can i contact you ? Or can you give me the steps to install the thermocam?

stevefleischer, 2018-05-20:
Hi,
I'm not sure if this is relevant to your problem but this was my experience. After I built my first camera and switched it on the screen was white. There was no boot up message or anything. Just a white screen. I checked the voltages on all the components and everything seemed OK so I was puzzled about what could be wrong. One of the last instructions in the assembly guide said to flash the firmware. I didn't think this was necessary because I had done this right at the beginning, before I soldered the Teensy onto the PCB. However, I didn't know what else to do at this point so I thought I would flash it again. The problem was that I couldn't access the button on the Teensy (because it was between the microcontroller and the PCB). I read some posts on this page and found one that mentioned accessing the Teensy using software called tytools (which was written by Koromix on GitHub). I downloaded it and ran it (on Windows 10) and it displayed the details of the Teensy board. I used the Upload button to flash the firmware again and after that the boot screen came up and the Thermocam started working.

So, in short, my camera had a white screen because I needed to flash the firmware a second time. I did this using tytools. I hope this helps.
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

nacerazel, 2018-05-20:
i had the same probleme before uploading the firmware, my toouchscreen shows me a message (first Booting and then a quick message which show me the devices that are ok and the ones failed, ( touch screen and spot senssor (i use lepton 2,5) ) and after this a message " please touch screen for your first use " is written but it doesn t respond,

stevefleischer, 2018-05-21:
I'll have to write this build off as a failure. Now it freezes on the boot message screen and then the LED starts to flicker, screen goes white. There seems to have been a problem with the battery right from the start but at least I got to the "Insert SD card" screen. Now I can't even get that. Although the battery reads 3.98V (supposedly 3.7V - 2000mAh) there was always a bootup message to say that the battery needed charging which I ignored. Furthermore, the Pololu 5V voltage regulator gets extremely hot - painfully so - and that can't be right.  As I am out of ideas now (I replaced the Pololu but it made no difference) I will have to admit defeat.

maxritter, 2018-06-05:
Seems like there is a short somewhere on the PCB, which can be very hard to identify.. Where did you get the PCB from, or did you produce it by yourself?

stevefleischer, 2018-06-05:
Thanks for your reply. I got the PCB from Smart Prototyping using the Gerber file your provide. They look very good and I don't think it is at fault. Initially I got to the boot up screen but it couldn't detect the SD card. I think I might have damaged something when I re-soldered the card reader tested the voltages on the board. Anyway, a bit pricey to buy the components and start again - at least for now. I'll shelve the project for a later date. My first build worked perfectly (this was my second build) so thanks for sharing your great project.

Closed 2018-06-05.

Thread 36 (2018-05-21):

Wrong Arducam delivered

Loremwriter, 2018-05-21:
Hello,

I wanted to build my own thermocam, but I got stuck because of the wrong parts. I used the links in the description, but I got some new version of the "Arducam 2MP Camera Shield“.
I used this link: https://www.ebay.com/itm/Arducam-Mini-module-Camera-Shield-w-2-MP-OV2640-for-Arduino-UNO-Mega2560-board-/281639729684

Unfortunately I bought it on eBay, but this camera doesn’t fit in the case.
I guess we need the version like IMG-1, but I got the „new“ version as seen on IMG-2.

IMG1:
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

IMG2:
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

Could you please tell me, how I can use the Version I got, or how I could get an "older" version of this camera?
Guess GroupGets still delivers the correct version, so where do they buy their stuff?

Can't imagine, that I'm the only with this issue. :)

Best regards :)

blotske, 2018-05-21:
I used the new version successfully.  I don't have a case for it yet though.  It will post the design files once completed.

Loremwriter, 2018-05-21:
@blotske : So you built it with V2 and it works?
Thought the position of the lens would have a big impact to the results. I had the idea to use a lens from another cam, instead of this one.

Seems to be a 1/4" diagonal 60 degree lens.

If anyone has any idea to this topic... Tell me.
And it would be nice, if you could post your design files, even thought my enclosures are cut already.

blotske, 2018-05-21:
The hybrid view is slightly off but not by much.

Loremwriter, 2018-05-26:
Update: I just drilled a hole with 15mm diameter into the front panel, works fine. :)

Closed 2018-05-26.

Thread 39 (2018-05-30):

Camera stopped working: can't identify the issue

JeremyG, 2018-05-30:
Hi,

I managed to build the cam, flash the firmware, and start the cam. I was on the calibration screen when I turned it off, intending to do the calibration on the following day. Then the next morning, the cam didn't start. I first thought it was a battery issue, but I tested it, it charged OK, until 4.10 / 4.20V approx., and then the light turned green.

However, the cam doesn't start anymore. The issue seems to come from the Teensy: can't see the orange control led anymore, and the tension between Vb and Gnd is around 1V, nothing more.

It may also be coming from the coin cell battery: I thought it may be drained and changed it. The new one half-drained quite quickly, and it didn't change the teensy issue.

What do you think my issue would be? Is the Teensy dead because of a short circuit or something I might have done involuntary? Could it be coming from the coin cell battery? Could I have damaged the PCB in some way?

I have an extra Teensy 3.6. Do you think I can go ahead and change it right now, or is there a way to identify the source of the issue first?

It's already a lot of questions so I leave it there :). Any help appreciated, thanks!

maxritter, 2018-06-05:
The coin cell battery is only responsible for the integrated real-time-clock, so it does not influence the boot of the device.

You should be able to measure around 5V between VIN and GND on the Teensy. If this is not the case, there is something wrong with the Pololu step-up booster. Also, the Teensy shoukd generate 3.3V between the 3V3 pin and GND.

If the supply voltages are stable and the backlight work, you might want to check the connections between the Teensy and the Display. In case the hardware is OK, try reflashing the firmware.

JeremyG, 2018-07-11:
It appears that I burned the microcontroller, probably after a bad handling of the battery causing a short-circuit. I changed the faulty components and re-built the cam, it's working now.

Closed 2018-07-11.

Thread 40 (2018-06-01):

"Trying to start..." on boot menu

Loremwriter, 2018-06-01:
Hi,

i ordered a new display, which is resistive instead of capacitive. At first, everything was fine. I got to a menu to set up the time and date, but then after restart my camera get stuck on the boot menu.
Here is the current screen. Every time I start up, it get stuck at this screen.
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

Does anyone has an idea, how to fix it?

I already flashed a new firmware to the camera (Version 2.46 from 17.04.2018).

Best regards

maxritter, 2018-06-05:
There seems to be an issue with the I2C bus, because all devices using it are shown as "Failed". So maybe there is a short somewhere or the 4.7k pullup resistors are not connected properly. Resoldering the affected connections also helps sometimes :)

Closed 2021-03-10.

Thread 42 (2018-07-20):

The camera is stuck with a screen that says "Please wait. ." whenever I try to access either cam

billgrava, 2018-07-20:
Each time I attempt to access either the thermal or visual camera, I get stuck with a white screen that says "Please wait. ." that does not change no matter how much time I give it. The self-diagnostic does not detect any errors with the cameras, so I am wondering if there is anything I should check for or if there is a reboot procedure I need to do. Thank you.

maxritter, 2018-07-22:
Have you been able to use the cam normally before?
When you flash the EEPROM_Clear script from here: https://www.dropbox.com/s/jqcwolz5vajj0u5/eeprom_clear.ino.hex?dl=1
And afterwards the newest firmware again, are you able to see the thermal and/or visual image during the first start procedure?

billgrava, 2018-07-23:
I flashed the EEPROM_Clear and then the new firmware again, but it did not seem to fix the problem. I have not been able to use the cam before. Initially when I was building the camera I put the IR sensor in the wrong way. I eventually took it out all together and have not put the IR Sensor back in. I understand that the thermal camera will not work but was hoping that the regular visual camera would.

himike12, 2018-10-31:
Were you able to resolve this problem? I am having the same issue with mine.

maxritter, 2018-11-05:
Are you using a non-radiometric Lepton with the MLX90614 spot sensor, or a radiometric without?

You should use a multimeter with the connection checker, and go through the important connection using https://github.com/maxritter/DIY-Thermocam/blob/master/Documents/Schematic_2.3.pdf and https://github.com/maxritter/DIY-Thermocam/blob/master/Documents/Pinmap_2.1.pdf.

The components that can cause a freeze in this screen are the visual camera, the Lepton and optionally the spot sensor. So check correct power supply and data connection lines (SPI & I2C) for those.

himike12, 2018-11-08:
Thank you maxritter for getting back to me.
I am using the radiometric Lepton without the spot sensor. I will confirm the connections.

HateFindingNames, 2019-08-18:
Same here. Lepton 2.5, no MLX installed, ArduCam 2MP plus version, newest firmware. All Supply and data connections already checked.
It stays at the self diagnostic screen forever giving me the message "trying to start..." unless is touch the screen.
Inside the menu is everything but everytime I try to get an image from visual or thermal it is just telling me to wait without anything happening ever. Touching the screen to get back into the menu works. Only the calibration screen makes the whole device freeze while it is stuck at 0%.

Do you have any suggestions?

maxritter, 2019-08-18:
@HateFindingNames Unfortunately, the issue is very hard for me to reproduce here. I have the unverified assumption that the radiometric version of the Lepton is not recognized correctly, so the device tries to connect to the non-existing MLX90614 spot sensor.

What you can try to verify this is install the SDK IDE by following the steps here: https://github.com/maxritter/diythermocam_firmware/

Then in lepton_init() under /src/hardware/lepton.cpp, print out whats the content of the variable leptonVersion after lepton_version() has been called (Serial.println(leptonVersion)). It should be 3 if the Lepton2.5 is recognized correctly.

HateFindingNames, 2019-08-19:
Thanks for the quick reply. I am at work right now but Iwill let you know as soon as I'm back.

HateFindingNames, 2019-08-20:
Ok, after some further investigation it turned out that in fact this lepton seems to be a non-radiometric version. Doh!
Is there a way to make use of it - for now - without haveing a MLXP attached?

maxritter, 2019-08-23:
Makes sense then. Unfortunately, if you use a non-radiometric Lepton, the DIY-Thermocam needs the MLX90614 attached to be working correctly.

HateFindingNames, 2019-08-23:
Ok, I'm going to order one and reply as soon as I know more.

It is easier for me to order at mouser. They got the MLX with the part-no 482-90614ESFBCF000SP.
On the picture it is missing the optics tube but the part description/specs are all the same compared to digikey. Do you happen to have any experience with the mouser part? Is it safe to order?

maxritter, 2019-08-25:
The part number is right, so I think they just used the wrong picture. Should be good to go :)

HateFindingNames, 2019-08-28:
Good news - MLX is the right one. More good news - it's working ;) thank you very much. I think you can consider this issue solved.

maxritter, 2019-08-30:
Perfect! I am glad it is working now :)

Closed 2019-08-30.

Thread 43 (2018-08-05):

EAGLE PCB image & schematics for DIY Thermocam V1

PriedeJ, 2018-08-05:
Hi,
can you please publish PCB drawings for old version of Thermal Cam V1 with Teensy 3.2 and the last firmware?
Thanks!

Closed 2018-08-25.

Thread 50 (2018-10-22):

Calibration stuck at 0%

leonardp, 2018-10-22:
Hi,

after the initial setup (setting date etc.) the screen shows the calibation screen stuck at 0%.
We waited for about 1minute or more but it did not change in any way.

Any hints on how to get more debug output out of the firmware or any other ideas how to tackle
this problem would be appreciated.

Thanks
Leo

maxritter, 2018-10-25:
Dear Leo,

are you using a non-radiometric version of the Lepton with the external spot sensor, or a radiometric Lepton?

If you are stuck in the calibration screen, it seems like the connection to the lepton and/or the spot sensor is not working. Please use a multimeter and check the lines between those components and the Teensy.

You could also flash this file (https://www.dropbox.com/s/jtglat0sg5msu17/NoCalibration.hex?dl=1) with the Teensy Loader (https://github.com/maxritter/DIY-Thermocam/tree/master/Software/Firmware%20Updater/Teensy%20Loader) and afterwards the newest firmware again to skip the calibration process. But if the Lepton or the spot sensor is not working, you may be stuck in the boot screen then.

Hope that helps!

Wishes,
Max

Meins321, 2019-05-13:
In my case the Lepton sensor was lose in the 90° pinheader and missing one solderspot (oops)

It was "calibrating" after i checked the lepton and the lasersensor

leonardp, 2020-09-10:
Turned out to be a defective MLX90614-BCF Spot Sensor.
Having Sanity checks for that would be nice to have in the firmware (if it isn't already implemented).

Closed 2020-09-10.

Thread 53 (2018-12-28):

Problems FIRST firmware installation

LenzoM, 2018-12-28:
Hello,

I can't install the firmware for the fist time in the camera. I have just assembled it all and so I want to flash the firmware.

With the updater from the software folder, and the last HEX files from the firware section. I connect the camera to the computer ( I have installed the DRIVE.exe) and I get these messages.

How do you see them?

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

LenzoM, 2019-03-07:
Hello Max!

Thank you for your reply :)

I, after some troubles, finally managed to connect the camera to de computer and finally I could reboot the hex file, until i get the message, from the teenesy program of OK. But, after that, my screen gets frozen in this picture and it doesn't seem likely to move on.

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

I wish you could help me!

stephen94000, 2019-03-25:
Hello, I'm currently facing the same problem as you do. Have you managed to bypass this screen ?

stephen94000, 2019-03-25:
I think this is somehow related to the hardware detection of the components in the device?

maxritter, 2019-03-25:
Dear @LenzoM , dear @stephen94000 ,

sorry for my late reply, I was on vacation. Stephen is right, this is most likely related to one or some of the hardware components not working / not connected properly.

Please use a multimeter and check all the connection to the sensors (SPI & I2C Lepton, I2C MLX90614 for non-radiometric, SPI & I2C camera). You could use those two documents for that purpose: https://github.com/maxritter/DIY-Thermocam/blob/master/Documents/Pinmap_2.1.pdf & https://github.com/maxritter/DIY-Thermocam/blob/master/Documents/Schematic_2.3.pdf. Also check if the supply voltage for all components is correct and the Lipo is fully charged.

If the problem still persists, you could install the Eclipse IDE, load the firmware project there and insert Serial Outprints at different stages of the startup procedure. This way you can identify where the procedure hangs up. Setting up the IDE is described here: https://github.com/maxritter/diythermocam_firmware

Let me know if this helps :)

Best,
Max

Meins321, 2019-05-08:
Mybe this helps and you can add it to the reository for people without eagle!

Is shows the traces from one spot to another
[PCB 2.3.pdf](https://github.com/maxritter/DIY-Thermocam/files/3156544/PCB.2.3.pdf)

LenzoM, 2021-02-25:
Thank you for your kind help! It works now fine!!
I have another issue, but i open now another topic

Closed 2021-02-25.

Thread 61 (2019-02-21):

Initial setup shows "Lepton2.5" when 3.5 is installed + note and question

BruXy, 2019-02-21:
Hi, I have join latest GroupGet campaing and finally assembled the camera. It is great project, congrats!

**1. I am just curious, initial setup showed "Lepton2.5", but I should have 3.5. Just for clarification, this is the picture of what I get:**

http://bruxy.regnet.cz/hamradio/diy_thermalget.jpeg

I have compared it with Digikey picture and it is Lepton 3.5 (not sure 100%, but looks same):

https://www.digikey.com/product-detail/en/flir-lepton/500-0726-01/500-0726-01-ND/6163867

I have dig little bit around source code and looks like, it is a feature:

https://github.com/maxritter/diythermocam_firmware/blob/master/src/gui/firststart.cpp#L302

**2. I had also problem with initial uploading of firmware in Linux**

I have used:

`./teensy_loader_cli -v --mcu=TEENSY36 -w  Firmware_V2.hex`

It was waiting for Teensy to appear, but to be able to upload firmware, I needed to press the reset button, a.k.a shorting P and G, which I have found here: https://github.com/maxritter/DIY-Thermocam/tree/master/Software/Firmware%20Updater

**3. Visual and thermal image position**

Should both images be perfectly aligned or it is more for just rough comparison?

My camera shows this: http://bruxy.regnet.cz/hamradio/thermalget_test.jpg

I am courious if it should be just rough or should I spend more time with alignint of both cameras together? But I was quite precise when puting all spacers under modules.

Thank you for answers and clarification!

clesys, 2019-03-03:
Hi BruXy,
maybe off topic, bt if you installed a radiometric Sensor like Lepton 2.5 or 3.5, you don't need the single-point infrared sensor.
Compare "AssemblyGuide" Step10

maxritter, 2019-03-25:
Dear @BruXy ,

let me answer your points:

1.: You are right, it's a typo in the screen message displayed. The device should have found out already you are using the leptonVersion_3_5_shutter variant of the sensor, if the thermal image is displayed correctly. @clesys is also right about the fact that you don't need the MLX90614 when using the Lepton2.5 or Lepton3.5, but it shouldn't affect the detection of the sensor. It's just not used by the firmware then.

2.: Thanks for the information. When flashing the firmware for the first time, depening on the OS it can happen that you need to short those two pins. I am glad it worked then.

3.: Due to the small paralaxe between camera and Lepton, the alignment depends on the distance to the scene / target. I am having different alignmnents saved for standard distance scenarios, like 1m, 5m, 10m. I find the combined mode helpful for a rough clue what objects in the normal image correspond to which in the thermal image, so I wouldn't spend too much time fine-tuning here.

Best,
Max

Closed 2019-11-27.

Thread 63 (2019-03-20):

ArduCAM-M-2MP Plus SPI Initialize issue

SenexCrenshaw, 2019-03-20:
I am having a really hard time for some reason finding a non-plus module. I received a ArduCAM-M-2MP Plus module and got spi errors when the firmware starts up. I even put just a demo app on the thermocam using pin 10 as the CS pin. Both ways i can see SPI initialization errors. Everything else works great. So i decided to try another camera and i got the same plus model... Same issue. I used my meter to make sure pin 10 does connect to the cs pin on the camera. So at this point I am not sure if its something wrong with my soldering which i did it twice or the board I received has something wrong with it..

Any ideas???

Awesome project btw. It works great but I would love to have it 100% functional.

kaimart, 2019-03-21:
Same here. Watterot only sells the plus model, old ones are out. I didn’t look for logs yet, on startup the software says „init failed“ for the visual camera.
Great project, however! I really appreciated the work on it with this very well documented order an build process. Thanks!

maxritter, 2019-03-25:
I was not aware there is a plus model, but seems like they changed something in the driver code there so it's not working with my implementation any more.

From the code changes in the Arducam repo alone I can't see whats the difference: https://github.com/ArduCAM/Arduino/tree/master/ArduCAM. The #define for OV2640_MINI_2MP_PLUS seems to behave the same than for the OV2640_MINI_2MP.

If someone can send me his module, I can fire up the IDE and see whats wrong. Please drop me an email to mail@maxritter.net for the shipping address.

Best,
Max

maxritter, 2019-04-27:
Firmware 2.48 should provide support for the ArduCAM-M-2MP Plus: https://github.com/maxritter/diythermocam_firmware/releases/tag/2.48

Closed 2019-04-27.

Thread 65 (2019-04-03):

Cam does not boot in battery mode

DavidWid, 2019-04-03:
Hi,

I completed my Thermocam build and I'm running into a weird problem right now.
When booting the camera when it's connected to a usb power suply, everything works fine.
But when I'm starting the cam without external power suply, the screen lights up I can hear (and see) the thermal sensor shutter closing and reopening, but the boot screen does not appear and the camera does not boot.
I'm by no means an electrical engineer, so I'm afraid I might have wired something wrong regarding the battery (thoug I'm quit sure I followed the instructions here).
Is there any way to toubleshoot whats wrong with my camera?

stephen94000, 2019-04-18:
Hey, I had the same trouble, However, by rewiring everything, it worked. Check if your battery is fully charged, Have you welded everything on a PCB or are you using a bread board ?

Closed 2021-03-10.

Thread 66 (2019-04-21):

Replacement for TP4057 charging module

KrisJot, 2019-04-21:
Hi,

can be used TP4056 as replacement for TP4057 from part list?

maxritter, 2019-04-27:
It does not exactly fit the holes on the PCB, but from the charging perspective, it should work. However, you need to solder cables to the LEDs on the module and remove them, if you want to use the charging light functionality.

KrisJot, 2019-04-30:
Thank you for reply. Will try and let you know about the result.

Meins321, 2019-05-08:
>
>
> It does not exactly fit the holes on the PCB, but from the charging perspective, it should work. However, you need to solder cables to the LEDs on the module and remove them, if you want to use the charging light functionality.

Maybe it is the better option?

I did buy the TP4057 off ebay with blue pcb, but i got the green pcb and it doesnt work. My lipo did not charge and the whole board just heated up like warm toast.
the teensy is dead now :-(

The lepton still works as i tested it with another socket

So don't use the green TP4057 which is delivered from ebay from many sellers

KrisJot, 2019-05-23:
Hi, TP4056 is charging properly (blue PCB). Lipo charged to 4.2V.

rossoe, 2023-01-25:
@Meins321
Is this the appropriate wiring for the TP4056 ?
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

rossoe, 2023-11-28:
See updates on this [post](https://github.com/maxritter/diy-thermocam/issues/103) for final tested wiring solution.

Closed 2021-03-10.

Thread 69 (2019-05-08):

Issue with initial Thermocam USB connection

FOC1902, 2019-05-08:
Dear Max, dear community,

first of all, thanks to that great project. It must have been a lot of research, time and work. Great job!
I was building the Thermocam the last couple of days and stumbled across an issue while connecting it to the computer the first time. Once I connect the Cam, the charging LED lights up. If I switch on the cam, the LED on the arduino starts blinking and the display turns on showing a white screen. Every ~30seconds, I can also hear the thermal image sensor clicking. And thats it, Window does not recognize the cam at all.
Not sure how to proceed further - is that behavior normal or do I have an error somewhere in HW?

Thanks,
Bastian

Meins321, 2019-05-09:
Maybe your battery is depleted and the usb charging port of you pc or laptop cant handle charging+startup?
Do you have the same behaviour on another pc/usb port? Did you charge the cam completely before it was connected to the usb port?

FOC1902, 2019-05-10:
Hi,

yes I charged the battery until the LED turned green. I also tried different USB ports and even another computer. Does anyone know if the behavior which I described above (display lights up with white background, clicking of the thermal image sensor etc.) is the standard behavior?
I appreciate any idea... thanks in advance

Meins321, 2019-05-13:
Sounds like this:
https://github.com/maxritter/DIY-Thermocam/issues/65

"the screen lights up I can hear (and see) the thermal sensor shutter closing and reopening"

maybe your lipo is bad or a solder connection, if it was mine i would open it and put a multimeter on the battery to see if it sagging on startup

You said: "Window does not recognize the cam at all." <- Teensy 3.6 micro usb connection broken? After all it is just mico usb, take out the plastic plate ontop of it an check maybe with another calbe/charger combo?

FOC1902, 2019-05-16:
Hi all,
I finally found the error. Seems like I had a bad welding connection somewhere at the switches, I re-welded them and now it works fine.
Cheers

Closed 2019-05-16.

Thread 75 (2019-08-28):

Last Time Buy Date	09/30/2019 LEPTON BREAKOUT BOARD EOL or Obsolete Part!!

Meins321, 2019-08-28:
@maxritter Got an E-Mail from Digikey:

Part Affected
--
Manufacturer | FLIR LEPTON
Description | LEPTON BREAKOUT BOARD PCB ASSY
Manufacturer Part Number | 250-0587-00
Digi-Key Part Number | 250-0587-00-ND

[Link](https://www.digikey.com/classic/ObsoletePart.aspx?dkcid=3163&WT.z_email=obsolete&pn=250-0587-00-ND)
Status | End Of Life
Last Time Buy Date | 09/30/2019
Substitutes | Please click here

blackdot, 2020-04-07:
Hello, this substitute has different pinout.
Did anyone managed to make everything work?

jonaswinterhalder, 2020-04-07:
Hi blackdot, im working on it. I just received the Breakout Board v2.

VoodooBane, 2020-05-01:
>
>
> Hi blackdot, im working on it. I just received the Breakout Board v2.

Any update on this? Would this [https://store.groupgets.com/products/purethermal-breakout-board] work as a drop in replacement for 250-0587-00?

Let me know I ordered the groupget "PureThermal Breakout Board" just in case

jonaswinterhalder, 2020-05-04:
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

Unfortunately I got a broken camera and could not continue testing. The camera is currently on its way to America. I'm sorry for the bad news.

Pesylizium, 2020-06-08:
Does anyone already have new information about the Breakout Board V2?

mdjonni, 2020-06-23:
> Does anyone already have new information about the Breakout Board V2?

Anyone got it working with the Breakout Board V2? I tried to setup mine matching all the pin outs. Whenever I go for live view, the screen just says "Please wait.. ". I'm using Lepton 2.5.

VoodooBane, 2020-06-28:
I was able to get my Leptop 3.0  to work with https://store.groupgets.com/products/purethermal-breakout-board
You need to bend the pins at an angle and then remove the  Vsync and EN Pins "This new board has two new pins, VSync and Enable" I used 3mm double-sided tape on the back of the board then soldering the pins together.

samirakle, 2020-07-02:
> I was able to get my Leptop 3.0 to work with https://store.groupgets.com/products/purethermal-breakout-board
> You need to bend the pins at an angle and then remove the Vsync and EN Pins "This new board has two new pins, VSync and Enable" I used 3mm double-sided tape on the back of the board then soldering the pins together.

Hi there. Do you know if that Pure Thermal breakout board will work on the Lepton 3.5? Also, for clarification, which pins did you solder together exactly? I'm assuming it was the 2 extra pins (VSYNC and EN)? Thanks.

VoodooBane, 2020-07-02:
That was my mistake I went all out as well and got the leptop 3.5. That is
correct I the 2 pins extra are VSYNC and E. just desolder those ones of.
yes been the pin and solder them. I will be back with a photo for you! and
ill link the tap I used.

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

samirakle, 2020-07-02:
@VoodooBane Okay thanks. Yes, a picture would be great to see. I'm currently working on this build but I was provided the FLIR breakout board V2 which has 2 rows of pins (total of 20 pins). The Pure Thermal breakout board should be on its way sometime soon. 👍🏼

VoodooBane, 2020-07-06:
The solder job:
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

And here is the Tape I used it on the battery and the pure thermal board to keep it in place soldering (I did cover the PCB and the back of the pure thermal board with Kapton take)
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

I hope this helps! I wish we could utilize the Vsync pin... The screen lags when moving :(

VoodooBane, 2020-07-06:
I forgot to mention you. @samirakle

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

samirakle, 2020-07-09:
@VoodooBane Thank you so much for posting a pic! I'll let you know if I have any issues.

Ailsamly, 2020-08-20:
> @VoodooBane Thank you so much for posting a pic! I'll let you know if I have any issues.

@samirakle @VoodooBane Hi friends, I am a new learner from Germany and I am also planning to build a small thermal camera and integrate to a mobile robot, if possible, can we get in touch with each other and have a discussion for some problems. I would be really appreciated if I can get your experienced suggestions in my initial period. Thank you very much! My email address is whumly1223@gmail.com. You are welcome to contact me!
Best,
Leyuan

Closed 2021-03-10.

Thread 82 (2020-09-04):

Thermocam Freezes

chick0n, 2020-09-04:
And another Question:

Sometimes my Thermocam freezes at Bootup or the Picture Freezes,and it completely locks up, and I have to Switch on and off.

I also Charged the Lipo to 100%, and made Batterie gauge Calibration. But nonetheless it reports, that the Batterie is almost Empty.

What could be the problem?

I built the thermocam with an "ArduCAM-M-2MP Plus", and the new V2 Lepton Breakout board:
https://store.groupgets.com/products/purethermal-breakout-board

I connected like this:
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

Is there a way, to completely erase the teensy including EEPROM / Calibration Data, and start over?

chick0n, 2020-09-05:
I still have the Freeze issues. I think it has to do with the ArduCAM-M-2MP Plus.

When I deactivate the Arducam, it works.

With Arducam on, I get freezes during bootup and operation.

The Camera produces "Garbage" Output too. After about 10sec warmup time, the Camera works correctly.

So either my Arducam is defect, or it has something to do with firmware implementation?

So I have to boot the thermocam with Arducam disabled, then enable the Arducam and wait 10sec for warmup. Then everything works Ok.

maxritter, 2020-09-06:
@chick0n Strange issues and hard to debug remotely.. It could be that the Arducam is faulty or the module received a HW upgrade that the firmware is not able to cope with..

If you can't fix the problem on your own, please drop me a mail to mail@maxritter.net, and we can see how we can handle the situation (sending the device to me for inspection f. ex.).

chick0n, 2020-09-07:
I ordered the Arducam directly from uctronics:
https://www.uctronics.com/camera-modules/camera-for-arduino/arducam-mini-module-camera-shield-w-2-mp-ov2640-for-arduino-uno-mega2560-board.html

Maybe the model is too "recent". :)

chick0n, 2020-09-09:
Its Hardware defect...when I heat up the Samsung RAM Chip with Hot-Air, it works.

So its Bad RAM Chip, or BGA Soldering Issue...

So maybe dont buy from uctronics....

chick0n, 2020-10-27:
Uctronics sent me an new Camera, for free...this one works OK so far...

ncbelov, 2021-01-25:
Need help! There is no image from the camera arducam 2mp plus-rev-A working camera checked on arduino uno. What needs to be changed in firmware 2.48 to make it work?

maxritter, 2021-03-10:
Closing the issue, glad it's working.

Closed 2021-03-10.

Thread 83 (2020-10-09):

Lepton 3.5

WolfZ, 2020-10-09:
Hi,
in the description it is stated the Lepton "including the radiometric versions (Lepton2.5 only at the moment)" are supported. Is this still correct or is Lepton 3.5 (the radiometric version) supported and the website slightly outdated.
Kind regards
Wolf

chick0n, 2020-10-14:
Yes...its fully supported.

2.45 (06.04.2018)
-Added support for radiometric Lepton3.5

I use a 3.5 too.

VoodooBane, 2020-10-15:
Really wish the Vsync pin could be used. The screen lags on regular
movement.

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

leoshmu, 2021-01-11:
@chick0n What breakout board did you use with the Lepton 3.5? The breakout board linked on the readme doesn't seem compatible with the 3.5

revnu, 2021-03-08:
Guys, could we please revive this project in some way? I was close to order all parts but stopped then I realized that the Breakoutboard is not produced any more. The Version 2 of the Lepton-Breakoutboard (250-0577-00 ) has 10 instead of 8 PINs, so it would not be compatible with the rest of the PCB-design I think. In other words that means that this poormans-thermocam is not available any more for "normal people", without re-building the circuit/casis.

Is there a chance we fork this in a way that part-availability is also take into consideration? Then this will be futureproof :)

revnu, 2021-03-08:
>
>
> @chick0n What breakout board did you use with the Lepton 3.5? The breakout board linked on the readme doesn't seem compatible with the 3.5

So maybe the Version2 of the breakout-board (250-0577-00) is supported? Is there any chance that the screwholes and the dimensions are identical so you could use the PCB. I saw, that the position of the sensor is slightly different, but that could be easy solved with another enclosure

maxritter, 2021-03-10:
I am working on a V3 of the Thermocam, that supports the new Lepton Breakout Board. Stay tuned ;)

helmarw, 2021-04-22:
cool project!
is the new Breakoutboard 2.0 already supported in the latest firmware 2.48 ?

maxritter, 2021-05-01:
@helmarw Thanks!
For the Breakout Board V2, you need PCB Version 3.0 and firmware version 3.0 from https://github.com/maxritter/DIY-Thermocam/releases/tag/3.0.0

helmarw, 2021-05-01:
oki, thnx!
is buydisplay.com the only shop where you can get this display?
or are there other compatible displays, which might be easier to get ?!
also the lipo-charger seems to be only available on aliexpress
both will take weeks if not months to arrive ...

maxzev, 2022-01-12:
I had the same problem, just couldn't find a display with "parallel" interface like in the manual and bought the cheapest display with regular SPI interface instead.  It works so far. The display is 320x240 SPI v2 (exact model kmrtm32032-SPI with ILI9341 touch). It has its own pinout and doesn't match the PCB, I had to connect it just with wires.  I did no changes in the source code and it works ok, also lags from time to time but nothing critical.  Not sure if it bcs of the display.

cymatics, 2022-09-20:
After many weeks of waiting for parts, figuring out some of the less obvious details in the instructions, etc, I finally got my board fully assembled this week.  I installed the latest firmware, and booted up "Display", "Touch", "Battery Gauge", and "SD Card" all read "OK".  "Flir Lepton" came up  "failed".  After a few restarts to test, I have determined the Module works when using my mini USB hookup, and that when i start up the DIY cam board, the module's shutter immediately closes, and stays closed until I power down.

Using Lepton Module 3.5 with Breakout board V2.

maxritter, 2022-09-23:
@cymatics I have answered you via mail ;)

Closed 2022-09-23.

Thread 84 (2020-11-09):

I can't make the Lepton Breakout Board 2.0 to work

Lionear1508, 2020-11-09:
Hello everybody,

I got my Lepton 3.5 from FLIR with the Breakout Board 2.0 (I tried to get the V1.4 but I think is obsolete and I found in this forum that somebody used this one: https://store.groupgets.com/products/purethermal-breakout-board but right now is sold out), I tried to make the connections like if I was connecting the V1.4 (I got the Datasheet of the V2.0), I solder some male-female jumpers to the PCB to can do some testing with this board but when I turn on the camera it just stuck in the logo and it says booting..... I was wondering if somebody can just help me with that or can give me an idea about what is happening.

I dont know if I explain my issues in a correct way or if this section is the right one, it's my first time in here, I apologize in advance.

I will thank you very much!!

VoodooBane, 2020-11-09:
I am the person that used the purethermal break out board. I do have a Breakout Board 2.0 as well.  But i would reccomend using dupont jumper wires to test before soldering the board onthe break out board the pins are pretty much Reversed. Use ur multimeter conductivity mode to make sure the pin out on the board is matching the Pins. Also to Note you prob have to solder bridge the jumpers on the back of the breakout 2.0 board to enable the pins. do not just snip pins make sure if the are using the jumpers that came with them then the conductivity mode testing showing the pins are actually going out to the 2.54mm pins. you what I am saying? The whole point the snipping the jumpers on the back for the board is so that the actual breakout baord and lay somewhat flush to the custom PCB. Also take you time and be patient. You do not want to ruin "my precious" lepton 3.5 (it is expensive and just sooooo tiny!!!! amazing!!!! Aka dont accidentally wire a data pin to a voltage pin. you know what i mean?Ask if you have any other questions and ill tryingto tinker with mine to see what i can do to help.

Lionear1508, 2020-11-11:
Hello @VoodooBane thanks for answer me!

I made it work yesterday, I saw the datasheet for the pinout and the pin number 2 is where I connected the voltage of my power supply, but nothing happened, so I found in the FLIR tutorials that you can use another two pins next to the lepton sensor for the power supply inputs, I just connected my 3.3V on it and the shutter just closed and opened! but still with no communication, I don't know why but I downloaded the program again (I did not modified anything) and it looks like it's working, maybe is my setup.

I really aprecciate that you take the time to answer.

VoodooBane, 2020-11-11:
Awesome glad to hear it!

On Wed, Nov 11, 2020 at 1:29 PM Lionear1508 <notifications@github.com>
wrote:

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

Closed 2020-11-11.

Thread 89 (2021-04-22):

Cam hangs on Boot Screen, Hardware Issue?

Catarallus, 2021-04-22:
Hello together,

my Thermocam won't boot, what I see is the Boot Screen. I guess it's is a hardware problem.

I use the PCB Rev 2.3 with the new Lepton Breakboard V2.0 (20 Pins) and the Lepton 3.5. I also noticed that the Diode on the Lepton Breakoutboard is in the wrong direction. I wired the Voltage source to J3 connector to solve this Problem.
The Arducam is from robotshop which look's like a litte bit different like in the assembly guide, but the pin assignment is the same. In the new BOM is no Arducam listed, is this part obsolet?
I have no MLX90614 installed because in don't need it, right?

The voltage on the Lepton Breakboard and the Arducam is about 5V.

Any suggestions what else I can do to fix the Problem?

maxritter, 2021-05-01:
Hey @Catarallus!

For the Lepton Breakout Board V2, you need the PCB 3.0 and the firmware version 3.0.
Then the Lepton3.5 will work out-of-the-box and you do not need the MLX90614.

Unfortunately the visual camera is not supported any more on V3, as it made some problems. But you can always use a regular camera and create combined images on the PC with the ThermoVision software.

Best,
Max

Catarallus, 2021-05-03:
Hi Max,

tank you for your fast reply.
Flashing Pre Compiled V3 failed with the Teensy Uploader. It seems the file can't be loaded, "unreadable" is shown in the Uploader Statusbar.

maxritter, 2021-05-05:
Hey @Catarallus,

do you use the Teensy 4.1 and the firmware loader from [here](https://github.com/maxritter/DIY-Thermocam/tree/master/Software/Firmware%20Updater)? Then it should work, just tried it out myself.

Best,
Max

Catarallus, 2021-05-05:
Hi @maxritter,

yes I use Teensy 4.1. The flash process is now succesfully, but it only works with the push button (it is not easy to push the button if the Teensy is soldered to the PCB already) But who cares.
After Power up the screen is black, now.
I use farther PCB Rev 2.3. The Lepton is contacted with some wires on the PCB, of course I payed attention to the correct Pins. (The Thermocam will be mounted on a drone, so it's not a Problem).
What are differents beetwen PCB Rev 2.3 and PCB 3.0? Do I really need the new PCB?

Primergi, 2021-05-05:
Hi! Are you sure Breakout Board V2 works? You need to remove the Thermocam, and measure the DC-DC voltage.Must be Vcc 1.2 v, Vcc 2.8 v, Vcc 3.0 v.

Catarallus, 2021-05-06:
Hi,

I here the a "click" noise from the Lepton, it sounds like a camera shutter.
Which measurement points I have to check?

greetings
Johannes

Primergi, 2021-05-06:
"Which measurement points I have to check?"
Photo of the Breakout Board on the back side please.

Catarallus, 2021-05-07:
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
![Uploading IMG_20210507_130102.jpg…]()

Primergi, 2021-05-07:
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

Primergi, 2021-05-07:
Sorry if something is unclear. I am Russian, and I use a translator :)

Jandroks, 2021-05-08:
From what you wrote it appears that you connected Teensy 4.1 to the PCB top and therefore nothing can work for you. I put together Thermocam v3. and it worked without any problems.

Catarallus, 2021-05-11:
@Jandroks
thanks for your comment.
The pinout between Teensy 4.1 & 3.6 seems the same. Do you also know my combination is not working?

Catarallus, 2021-05-11:
@Primergi
> Sorry if something is unclear. I am Russian, and I use a translator .

I understand your suggestion. I will do the measurement if I had time to go ahead with this project.

Closed 2023-05-06.

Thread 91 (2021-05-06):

MTP device Windows 10

helmarw, 2021-05-06:
hi,

i just got my teensy 4.1 and first wanted to try out loading the firmware.
so i plugged it in and loaded the v3 hex-file (using Teensy Loader 1.52 under macOS) no error.
then in unplugged it, put a 2GB SD card in (formatted with SD Formatter, FAT16)
and plugged it into a Windows 10 PC (since macOS doesnt handel MTP device
Device is being recognized but i cant access the filesystem ... (reinstalled MTP drive too...)
even if nothing is connected to the teensy (except the SD card) shouldn't i be able to access its filesystem at least ?
Best
Helmar

maxritter, 2021-05-06:
@helmarw The MTP mode is not activated at startup automatically. Instead when the device is turned on and a USB cable is inserted, a prompt on the screen asks the user whether he(she wants to transfer files. Only then the Thermocam switches to MTP mode.
So I assume that everything related to the flash is working and also your SD card does, but you need the display attached to verify it.

helmarw, 2021-05-06:
ic, thnx a lot!
then ive to wait for the display :/

helmarw, 2021-05-07:
you dont happen to have a display left over ?

psarossy, 2021-07-27:
With the latest 3.0.2 firmware, I'm not getting the prompt on Windows 10 (or MacOS).

Verified that another MTP device (Sony camera) does show up as expected on Win10 with the same cable.

maxritter, 2021-07-31:
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

I just re-checked MTP functionality on 3.02, but it should work as expected:

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

You have to turn the camera on and have it in live mode. Then insert the USB cable and the USB File Transfer prompt appears on the screen. Choose "Yes" and afterwards you will see the "Teensy" device under your Computer. In case there is a driver missmatch, try to install this one: https://www.pjrc.com/teensy/serial_install.exe. Also make sure that the SD Card has 16GB or less and Class4 or Class10 (preferred). You can try to format the card on your PC first with a tool like SdFormatter: https://www.sdcard.org/downloads/formatter/

Let me know if this works for you :)

psarossy, 2021-07-31:
After fixing my power regulator issue, and unplugging and re-plugging the cord, eventually I got the pop-up, and was able to make the transfer work.

Closed 2023-05-06.

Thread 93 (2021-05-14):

finished my Themocam, a few remarks for the Enclosure

helmarw, 2021-05-14:
got my display finally :)
every thing is working fine !

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

i decided to 3D-print the enclosure first before i order a laser cut (if any)
good thing i did, since then i noticed few misalignments.

1) the opening for the USB-Port is to high
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

i also used a different t-Nut, because i could not get the one you suggested. only some minor modification nessesary.

2) the hole for the LED has to be 1-2mm more to the center or you need to leave the wires longer
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

3) most important, the hole for the Lepton is a bit low, i saw the upper edge of the housing in the thermal image
so i cut it a bit higher
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

4) i really didnt like the round head philips screws, so i used black A2 countersunk torx-screws. I think it gives it a nicer finish

helmarw, 2021-05-15:
i forked your project and added my modifications to my fork. Also added BOMs to all parts i bought
Feel free to use it, if you find it useful...

due to minimum order amount I also have 2 PCBs, 2 Lipo Chargers and a couple of T-nuts left over
if anyone is interested please drop me a line

maxritter, 2021-05-16:
@helmarw Great to hear it's working now!

The 3D printed enclosure looks great and thanks for the mentioned improvements. I have widened the Lepton cutout a bit to the top as you have suggested, and also slightly extended the microUSB port. Concerning the Charging LED, I am wondering if you have soldered it on the "right" side of the PCB. Maybe this was a bit clear in the first version of the assembly guide, I have updated the guide today with fresh images: https://www.diy-thermocam.net/build-your-own

helmarw, 2021-05-16:
hi, thnx for the reply
i checked again, i soldered the LED on the correct side of the pcb (other wise it would not hit the hole at all).
in the picture it looked like it needed to be as close as possible to the PCB, but in fact it needs a distance of 1-2mm.
so its better to mount  two or three sides of the housing to the PCB (on the display side) and then try inserting the LED
with 90deg bent leads. once its fits in the hole you can solder it.
in my case the leads are very short, almost flush with the PCB, thats how i interpreted your pictures. A higher res side view of the LED would have be helpful here, to see that the LED needs a bit space to the PCB
Now the LED sits at a aprox. 30deg angle inside the hole. its still working but, so i leave it as it is.

helmarw, 2021-05-18:
i updated my housing again: https://github.com/helmarw/DIY-Thermocam/tree/master/Images
i put all the stl und dxf files in my fork too

USB-Port fits nicely now
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

LED a bit better now, not perfect but close enough
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

front with an 8mm hole
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

and added a webcam-cover as lens protection :)  [simple 8mm one from Amazon](https://www.amazon.de/dp/B081J8D756/ref=cm_sw_em_r_mt_dp_3EE2QM3QVHKHH0B3Y5TW?_encoding=UTF8&psc=1)
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

IAowSwels, 2021-06-23:
Did you already covered these improvements in the latest CAD files?

Closed 2023-05-06.

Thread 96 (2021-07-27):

Step up converter overheating and powering down on battery

psarossy, 2021-07-27:
I've just received my Lepton 3.5 sensor, and finished the assembly.

The unit boots up, works for a few seconds, then the screen turns white and starts "blinking" in tandem with the red LED. Leaving the unit offline for some time, it works again for a few seconds, if I retry immediately it starts booting, it goes back to the loop immediately.

This lead me to believe that there's a thermal issue with a component, and it seems that If I use the built in battery, the 5V step up converter overheats and shuts down at around 110C, then the board enters a reboot loop as the power rails are not stable.

It runs fine on USB power if I don't flip the power switch.

Video: https://photos.app.goo.gl/JVPJjzPG8Rtgwq3A6

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

Thermal image
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
(can't get the raw file due to https://github.com/maxritter/DIY-Thermocam/issues/91#issuecomment-887789566)

maxritter, 2021-07-31:
Sorry to hear you are having an issue with the device. I haven't heard of this issue so far, all V3 customers have reported a working device since now. But it's always possible there is a faulty component..

- Have you verified with a multimeter that at step 3 of the [assembly guide](https://www.diy-thermocam.net/build-your-own), the two mentioned pins are separated?
- Does the Lipo Charger work, e.g. what is the voltage that you measure on the Lipo battery after it is fully charged?
- What is the voltage that you can measure between the middle pin and left/right pin of the Booster?

Let us debug this together, I hope we can get your device to work soon :)

psarossy, 2021-07-31:
Apparently this was a complete user error, apologies for wasting your time...

I did cut score the connection between the pads and remember measuring it, apparently I didn't score it deeply enough and there was a tiny, high resistance path still there, which was enough to mess with the regulator...

Scored it a few more times, and the resistance now is infinity \o/ and the regulator warms up but no longer overheats.

Closed 2021-07-31.

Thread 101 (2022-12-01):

Building Instructions v3 Feedback: LED, Lipo Protector, Switch, Heatshrink, Slide Cover

rduplain, 2022-12-01:
Hello! The thermocam, kit, and documentation are most excellent! After assembling a v3 kit, here are areas that could be improved in the documentation. Each topic is a simple suggestion to say emphasized sentence in the docs.

* **LED (14, 15).** _The LED needs to be soldered with enough lead wire to bend it 90 degrees upward and extend beyond the PCB._ I let gravity decide when soldering, attaching at the position in which the LED wire was already bent. The result was too short, which I only discovered after using a flush cutter, so I had to shave the LED and PCB in order to fully bend 90 degrees.
* **Lipo Protector (23).** _If desired, trim excess from the Lipo Protector with scissors before removing any protection foil. It just needs to be slightly bigger than the Lipo battery._ It's much more difficult to cut once the protection foil is removed, and the Adafruit lipo is smaller than the Samsung shown in the pictures.
* **Switch (30).** _Solder the wires perpendicular/horizontal to the switch, as there will be very little clearance once assembled, and ensure that enough insulation stays in tact to avoid shorting the two wires if they cross._ I needed to resolder these, and while they weren't touching, I used self-fusing silicone tape to ensure enough insulation.
* **Heatshrink (31).** _Make the heatshrink tubes as small as needed to cover the pads, as the button enclosure is a tight fit once the screen is added._ The heatshrink is only so flexible, and this put a lot of strain anytime I reseated the screen during the build, breaking the solder joint at the PCB multiple times until the heatshrink was broken in enough.

Ultimately, I found the slide cover ("Lepton Enclosure Protector") in the kit was not usable as it would result in a "vignette" of heat in the resulting image (i.e. the sensor was seeing the cover when either opened or closed). I reseated the cover in every position and orientation I could think of before finally giving up and discarding it.

The firmware instructions are a bit vague. The build instructions send you [here](https://github.com/maxritter/DIY-Thermocam/tree/master/Software/Firmware%20Updater) which doesn't make obvious what the steps are. This wasn't an issue as I've used Teensy before: (a) press the button the board to enter programming mode, (b) `teensy_loader_cli -w --mcu=TEENSY41 firmware.hex` (I'm using the Teensy CLI, not the GUI).

The build instructions could suggest not adding the plate (called "backside") until after firmware is flashed, because you'll have to take it off to access the button to put the microcontroller into programmer mode.

Altogether, the build instructions are great as is. I had no problem putting the kit together and starting to get thermal images!

Thanks!

PS: I don't see the source of https://www.diy-thermocam.net/building-instructions/ posted anywhere, else I would have submitted a patch.

maxritter, 2023-05-06:
Hey @rduplain,

sorry for the late reply, I have not been very active on this project for some months.

Thanks a lot for the detailed feedback on how to further improve the guide. I have included the changes in the latest version of the manual. The website now also has its own repository to give feedback: https://github.com/maxritter/diy-thermocam-website

rduplain, 2023-05-06:
Great, thank you! :rocket:

Closed 2023-05-06.

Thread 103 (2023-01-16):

TP4057 Charging module no longer available

rossoe, 2023-01-16:
Hi
I'm searching for TP4057 and I've only seen stock of below item in India with no international shipping available.
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

This is the only similar part I can find in UK on ebay:
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
But it's holes are in different locations so would not match the pins on motherboard.

What is best option? Can above be hacked to fit with wires rather than relying on pins?

Gilabite, 2023-01-16:
I used a TP4056, no mods to the board needed. these are what I used https://www.amazon.com/gp/product/B00LTQU2RK/ref=ppx_yo_dt_b_search_asin_title?ie=UTF8&psc=1

rossoe, 2023-01-16:
Ah yes I just spotted someone mentioning the use of TP4056 here - https://github.com/maxritter/DIY-Thermocam/issues/66
They gave a little detail re the schematic:
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

I'm fairly new to electronics so just to confirm is this how it should end up - I assume the cables to the rear LIPO holes ensures it makes use of reverse polarity protection on charging board?:
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

maxritter, 2023-05-06:
There is indeed no way to source the TP4057 anymore. Thanks for the instructions how to make it work with the TP4056. I have included this as the default part in the partlist now.

rossoe, 2023-11-23:
ok a little update as I just finished putting it together and now have what I think is the correct setup, this keeps all the wiring on one side of the pcb, as there was not much room between case and pcb to have wires around the back connecting the lipo battery as per discussions in this [thread](https://github.com/maxritter/diy-thermocam/issues/66).
The wires to the LED also allowed me to get both green and blue working which reflects both 'charging' and 'full' states for battery.
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

maxritter, 2023-11-25:
@rossoe Thanks for the detailed update with the images and I am glad it works this way!

chrisp429, 2023-12-06:
Do you think TC4056 with usb-C would suit? I would prefer to use a usb-C cable instead of mirco USB.
Eg:
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
like this one:
https://www.amazon.it/Aideepen-Interfaccia-ingresso-caricabatterie-protezione/dp/B0BZS73V5T/
or

rossoe, 2023-12-06:
I've used that one, however as you can see from the pics above the intended charging slot facing out is the Micro USB on the teensy 4.1 microcontroller which has corresponding hole cut out on the case, so unless you use the whole unit without a case it's not really practical to rotate the charge controller board and make a new hole in the case for it.

chrisp429, 2023-12-06:
> I've used that one, however as you can see from the pics above the intended charging slot facing out is the Micro USB on the teensy 4.1 microcontroller which has corresponding hole cut out on the case, so unless you use the whole unit without a case it's not really practical to rotate the charge controller board and make a new hole in the case for it.

Thank you rossoe, it is correct, I hanen't assembled one yet, so I was confused :).
Chris

Closed 2023-05-06.

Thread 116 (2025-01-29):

Help Needed, When I power on the display is all white and nothing ever comes on display

Atlantis3, 2025-01-29:
Hii everyone
I build the thermocam with all the instructions carefully and when i loaded the firmware the display powers on but then nothing happens, it just stays white all the time. There is no logo or anything.

I then connected the device to Thermocam Live Viewer, it says the device connected and then asks me to put the device in live mode.

Also just something i noticed is that the Lepton closes and opens the shutter when I Power it ON

Could someone help where the problem might be or is my display defective

Thank you very much in advance

maxritter, 2025-01-29:
Hey @Atlantis3,

welcome to the project, let's get your device to work! Please use the conncection checker of your multimeter and verify the data pins of the display connector are all properly routed to the respective pins on the Teensy 4.1: https://www.diy-thermocam.net/docs/hardware/

Also verify the 3.3V and 5V voltage for the display are properly working. The Lepton shutter trigger on start is normal and expected, so at least the Lepton has proper power supply.

Best,
Max

Atlantis3, 2025-01-29:
Hey hii @maxritter
Thank you very much for your answer. The problem was with my soldering on teensy. I replaced it with other one that had good soldering and everything now worked out properly and the device boots up.

Thanks
Akram

maxritter, 2025-01-29:
Glad you found the solution that quickly! Enjoy your DIY-Thermocam!

Closed 2025-01-29.

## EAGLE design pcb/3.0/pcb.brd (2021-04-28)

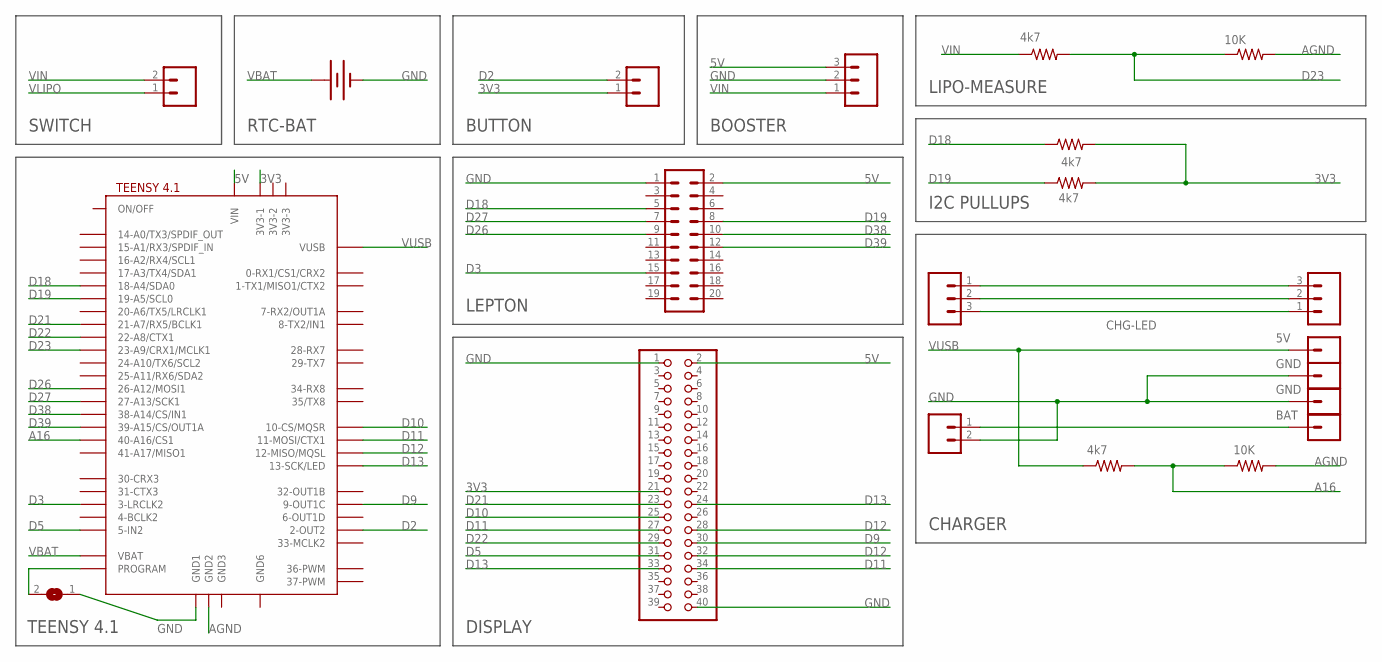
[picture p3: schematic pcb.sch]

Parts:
BAT: BATTERY12PTH; BATTCON_12MM_PTH
BOOSTER: M03PTH; 1X03
BUTTON, BUTTON1: M02PTH; 1X02
CHG-LED: M03PTH; 1X03
J2: CONN_10X2NOSILK; 2X10_NOSILK
JP1, JP2, JP3, JP4: M01PTH; 1X01
LASER1: M03PTH; 1X03
LCD-HEADER: PINHD-2X20; 2X20
PROGRAM: SJ
R1, R3, R4, R6: 4k7; AXIAL-0.4
R2, R5: 10K; AXIAL-0.4
SWITCH: M02PTH; 1X02
U$2: TEENSY41-E; TENNSY41-E

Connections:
3V3: BUTTON.1, LCD-HEADER.21, R4.P$2 (2), R6.P$2 (2), U$2.3V3-1
5V: BOOSTER.3, J2.2, LCD-HEADER.2, U$2.VIN
A16: R3.P$2 (2), R5.P$1 (1), U$2.40-A16/CS1
AGND: R2.P$2 (2), R5.P$2 (2), U$2.GND2
D2: BUTTON.2, U$2.2-OUT2
D3: J2.15, U$2.3-LRCLK2
D5: LCD-HEADER.31, U$2.5-IN2
D9: LCD-HEADER.30, U$2.9-OUT1C
D10: LCD-HEADER.25, U$2.10-CS\MQSR (10-CS/MQSR)
D11: LCD-HEADER.27, LCD-HEADER.34, U$2.11-MOSI/CTX1
D12: LCD-HEADER.28, LCD-HEADER.32, U$2.12-MISO/MQSL
D13: LCD-HEADER.24, LCD-HEADER.33, U$2.13-SCK/LED
D18: J2.5, R4.P$1 (1), U$2.18-A4/SDA0
D19: J2.8, R6.P$1 (1), U$2.19-A5/SCL0
D21: LCD-HEADER.23, U$2.21-A7/RX5/BCLK1
D22: LCD-HEADER.29, U$2.22-A8/CTX1
D23: R1.P$2 (2), R2.P$1 (1), U$2.23-A9/CRX1/MCLK1
D26: J2.9, U$2.26-A12/MOSI1
D27: J2.7, U$2.27-A13/SCK1
D38: J2.10, U$2.38-A14/CS/IN1
D39: J2.12, U$2.39-A15/CS/OUT1A
GND: BAT.GND (-), BOOSTER.2, BUTTON1.2, J2.1, JP1.1, JP2.1, LCD-HEADER.1, LCD-HEADER.40, PROGRAM.1, U$2.GND1
unnamed: CHG-LED.3, LASER1.1
unnamed: CHG-LED.2, LASER1.2
unnamed: CHG-LED.1, LASER1.3
unnamed: PROGRAM.2, U$2.PROGRAM
VBAT: BAT.VCC@1 (+), U$2.VBAT
VIN: BOOSTER.1, R1.P$1 (1), SWITCH.2
VLIPO: BUTTON1.1, JP3.1, SWITCH.1
VUSB: JP4.1, R3.P$1 (1), U$2.VUSB

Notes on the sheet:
CHARGER
DISPLAY
TEENSY 4.1
LEPTON
BUTTON
RTC-BAT
SWITCH
LIPO-MEASURE
BOOSTER
GND
BAT
I2C PULLUPS

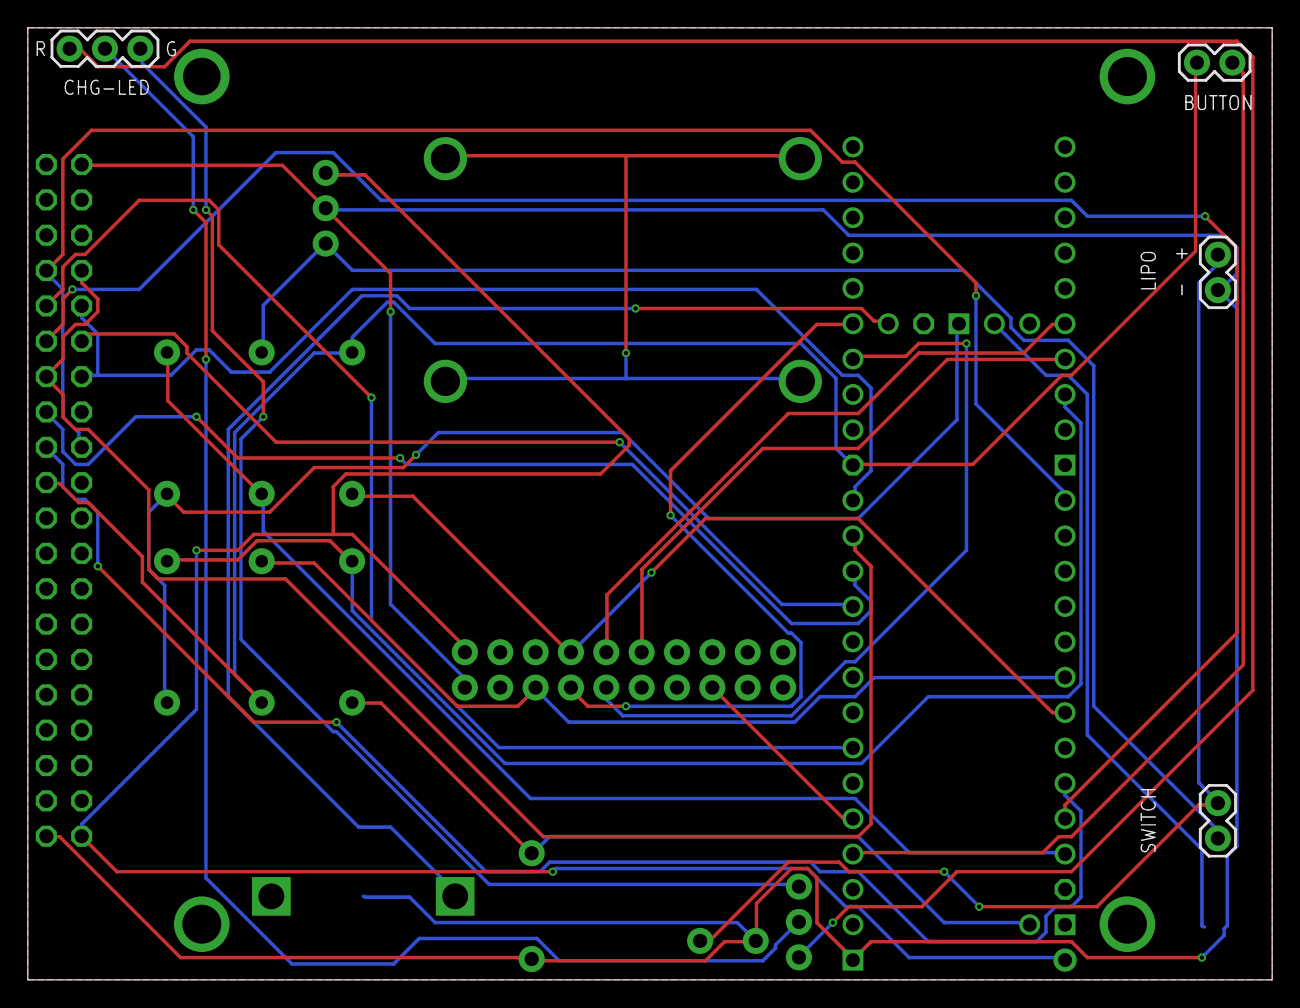
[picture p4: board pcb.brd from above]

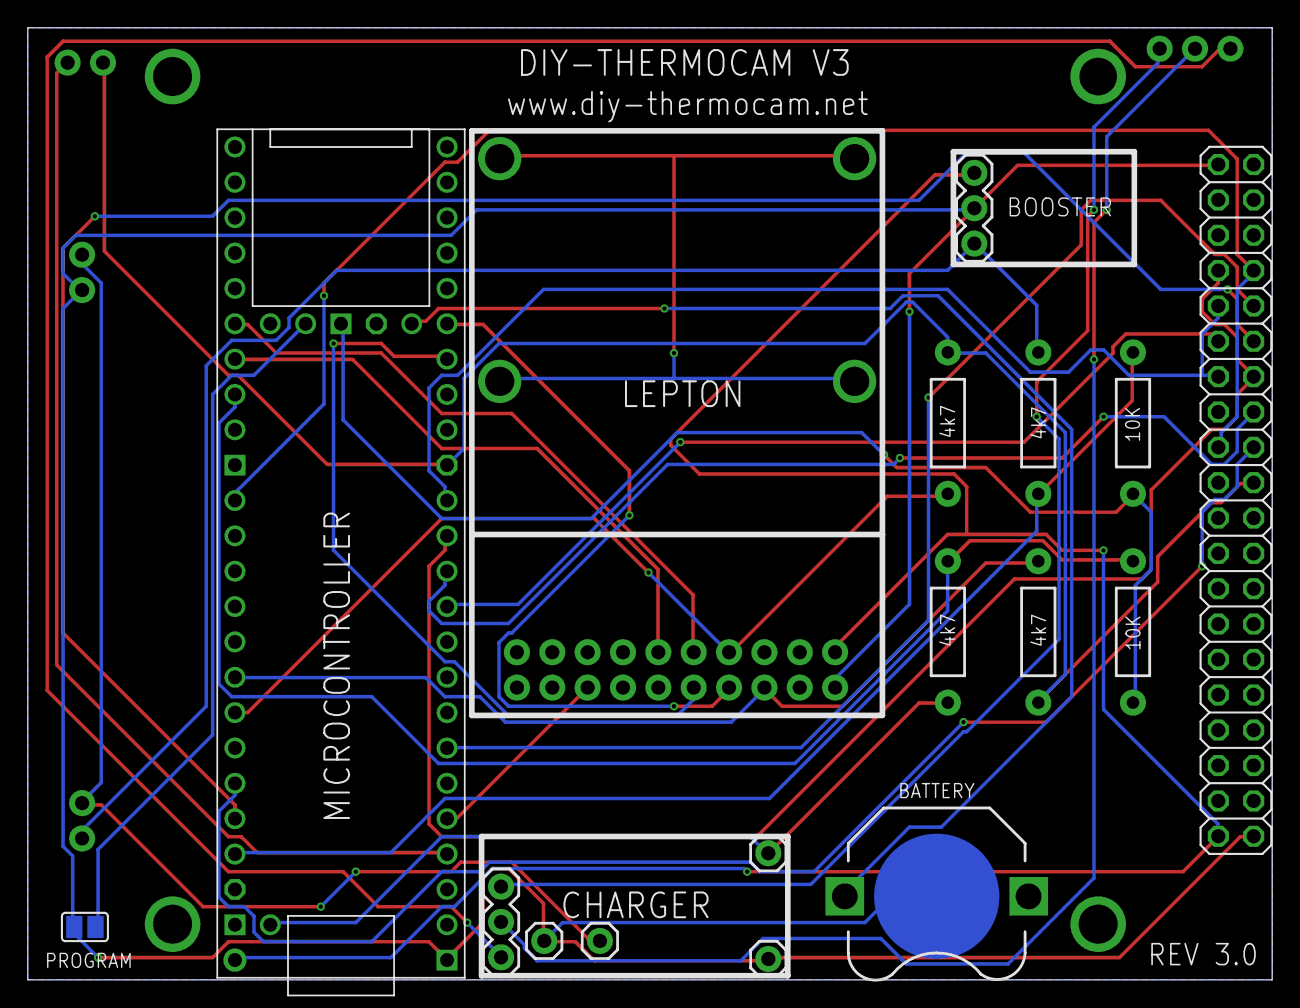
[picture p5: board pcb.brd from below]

Board: 2 copper layers, 89.4 x 68.4 mm, 21 parts (16 on the bottom side), 30 nets.

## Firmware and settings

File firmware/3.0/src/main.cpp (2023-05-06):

/*
*
* MAIN SKETCH - Main entry point for the firmware
*
* DIY-Thermocam Firmware
*
* GNU General Public License v3.0
*
* Copyright by Max Ritter
*
* http://www.diy-thermocam.net
* https://github.com/maxritter/diy-thermocam
*
*/

/*################################# INCLUDES ##################################*/

#include <Arduino.h>
#include <connection.h>
#include <firststart.h>
#include <thermal.h>
#include <hardware.h>

/*######################## PUBLIC FUNCTION BODIES #############################*/

/* Main entry point */
void setup()
{
	//Init the hardware components
	initHardware();

	//Check for firmware upgrade done
	checkFWUpgrade();

	//Enter USB connection if no display attached
	if (checkNoDisplay())
		serialInit();

	//Check for hardware issues
	checkHardware();

	//Do the first start setup if required
	if (checkFirstStart())
		firstStart();

	//Read all settings from EEPROM
	readEEPROM();

	//Show the live mode helper if required
	if (checkLiveModeHelper())
		liveModeHelper();

	//Go to the live Mode
	liveMode();
}

/* Loop not used */
void loop()
{
}

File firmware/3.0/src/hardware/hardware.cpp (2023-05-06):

/*
 *
 * HARDWARE - Main hardware functions
 *
 * DIY-Thermocam Firmware
 *
 * GNU General Public License v3.0
 *
 * Copyright by Max Ritter
 *
 * http://www.diy-thermocam.net
 * https://github.com/maxritter/diy-thermocam
 *
 */

/*################################# INCLUDES ##################################*/

#include <Arduino.h>
#include <globaldefines.h>
#include <globalvariables.h>
#include <SdFat.h>
#include <sdcard.h>
#include <gui.h>
#include <settings_defines.h>
#include <EEPROM.h>
#include <display.h>
#include <massstorage.h>
#include <TimeLib.h>
#include <touchscreen.h>
#include <Wire.h>
#include <battery.h>
#include <temperature.h>
#include <lepton.h>
#include <firststart.h>
#include <hardware.h>

/*######################## PUBLIC FUNCTION BODIES #############################*/

void t4_direct_write_low(volatile uint32_t *base, uint32_t mask)
{
	*(base + 34) = mask;
}

void t4_direct_write_high(volatile uint32_t *base, uint32_t mask)
{
	*(base + 33) = mask;
}

bool isUSBConnected()
{
	return (analogRead(pin_usb_measure) > 50);
}

/* Converts a float to four bytes */
void floatToBytes(uint8_t *farray, float val)
{
	union
	{
		float f;
		unsigned long ul;
	} u;
	u.f = val;
	farray[0] = u.ul & 0x00FF;
	farray[1] = (u.ul & 0xFF00) >> 8;
	farray[2] = (u.ul & 0xFF0000) >> 16;
	farray[3] = (u.ul & 0xFF000000) >> 24;
}

/* Converts four bytes back to float */
float bytesToFloat(uint8_t *farray)
{
	union
	{
		float f;
		unsigned long ul;
	} u;
	u.ul = (farray[3] << 24) | (farray[2] << 16) | (farray[1] << 8) | (farray[0]);
	return u.f;
}

/* Clears the whole EEPROM */
void clearEEPROM()
{
	for (unsigned int i = 100; i < 250; i++)
		EEPROM.write(i, 0);
}

/* Checks if a FW upgrade has been done */
void checkFWUpgrade()
{
	//If the first start setup has not been completed, skip
	if (checkFirstStart())
		return;

	//Read current FW version from EEPROM
	uint16_t eepromVersion = ((EEPROM.read(eeprom_fwVersionHigh) << 8) + EEPROM.read(eeprom_fwVersionLow));

	//Show message after firmware upgrade
	if (eepromVersion != fwVersion)
	{
		//Set EEPROM firmware version to current one
		EEPROM.write(eeprom_fwVersionHigh, (fwVersion & 0xFF00) >> 8);
		EEPROM.write(eeprom_fwVersionLow, fwVersion & 0x00FF);

		//Show downgrade completed message
		showFullMessage((char *)"Firmware update completed!");
		delay(1000);
	}
}

/* Reads the old settings from EEPROM */
void readEEPROM()
{
	byte read;
	//Temperature format
	read = EEPROM.read(eeprom_tempFormat);
	if ((read == tempFormat_celcius) || (read == tempFormat_fahrenheit))
		tempFormat = read;
	else
		tempFormat = tempFormat_celcius;

	//Color scheme
	read = EEPROM.read(eeprom_colorScheme);
	if ((read >= 0) && (read <= (colorSchemeTotal - 1)))
		colorScheme = read;
	else
		colorScheme = colorScheme_rainbow;

	//Convert Enabled
	read = EEPROM.read(eeprom_convertEnabled);
	if ((read == false) || (read == true))
		convertEnabled = read;
	else
		convertEnabled = false;

	//Battery Enabled
	read = EEPROM.read(eeprom_batteryEnabled);
	if ((read == false) || (read == true))
		batteryEnabled = read;
	else
		batteryEnabled = false;

	//Time Enabled
	read = EEPROM.read(eeprom_timeEnabled);
	if ((read == false) || (read == true))
		timeEnabled = read;
	else
		timeEnabled = false;

	//Date Enabled
	read = EEPROM.read(eeprom_dateEnabled);
	if ((read == false) || (read == true))
		dateEnabled = read;
	else
		dateEnabled = false;

	//Storage Enabled
	read = EEPROM.read(eeprom_storageEnabled);
	if ((read == false) || (read == true))
		storageEnabled = read;
	else
		storageEnabled = false;

	//Spot Enabled, only load when spot sensor is working
	read = EEPROM.read(eeprom_spotEnabled);
	if ((read == false) || (read == true))
		spotEnabled = read;
	else
		spotEnabled = false;
		
	//Filter Type
	read = EEPROM.read(eeprom_filterType);
	if ((read == filterType_none) || (read == filterType_box) || (read == filterType_gaussian))
		filterType = read;
	else
		filterType = filterType_gaussian;

	//Colorbar Enabled
	read = EEPROM.read(eeprom_colorbarEnabled);
	if ((read == false) || (read == true))
		colorbarEnabled = read;
	else
		colorbarEnabled = true;

	//Text color
	read = EEPROM.read(eeprom_textColor);
	if ((read >= textColor_white) && (read <= textColor_blue))
		textColor = read;
	else
		textColor = textColor_white;

	//Horizontal mirroring
	read = EEPROM.read(eeprom_rotationHorizont);
	if ((read == false) || (read == true))
		rotationHorizont = read;
	else
		rotationHorizont = false;

	//Hot / cold mode
	read = EEPROM.read(eeprom_hotColdMode);
	if ((read >= hotColdMode_disabled) && (read <= hotColdMode_hot))
		hotColdMode = read;
	else
		hotColdMode = hotColdMode_disabled;

	//Hot / cold level and color
	if (hotColdMode != hotColdMode_disabled)
	{
		hotColdLevel = ((EEPROM.read(eeprom_hotColdLevelHigh) << 8) + EEPROM.read(eeprom_hotColdLevelLow));
		hotColdColor = EEPROM.read(eeprom_hotColdColor);
	}
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

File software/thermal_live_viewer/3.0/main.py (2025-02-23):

from typing import Optional
import pygame
from src.liveviewer import LiveViewer
import serial.tools.list_ports as ports


def create_port_menu() -> Optional[str]:
    """
    Create a Pygame-based menu for serial port selection.
    
    Returns:
        Optional[str]: Selected port device path or None if selection was cancelled
    """
    pygame.init()
    
    # Calculate required window size based on content
    com_ports = list(ports.comports())
    max_port_length = max(len(str(port.device)) for port in com_ports) if com_ports else 20
    window_width = max(600, max_port_length * 15)  # Ensure minimum width of 600px
    window_height = 100 + len(com_ports) * 40  # Height based on number of ports
    
    screen = pygame.display.set_mode((window_width, window_height))
    pygame.display.set_caption("Serial Port Selection")
    
    # Setup fonts and colors
    font = pygame.font.Font(None, 36)
    text_color = (220, 220, 220)
    highlight_color = (100, 150, 255)
    bg_color = (30, 30, 30)
    selected_bg_color = (50, 50, 50)
    
    if not com_ports:
        pygame.quit()
        raise RuntimeError("No serial ports found!")
    
    selected_index = 0
    clock = pygame.time.Clock()
    
    while True:
        screen.fill(bg_color)
        
        # Draw title with more standard arrow notation
        title = font.render("Select Serial Port (Use Up/Down, Enter to select)", True, text_color)
        screen.blit(title, (20, 20))
        
        # Draw port options
        for idx, port in enumerate(com_ports):
            # Draw selection background
            if idx == selected_index:
                pygame.draw.rect(screen, selected_bg_color, 
                               (15, 65 + idx * 40, window_width - 30, 35))
            
            # Draw port information
            port_text = f"{port.device} - {port.description}"
            color = highlight_color if idx == selected_index else text_color
            text = font.render(port_text, True, color)
            screen.blit(text, (20, 70 + idx * 40))
        
        pygame.display.flip()
        clock.tick(60)  # Limit to 60 FPS
        
        for event in pygame.event.get():
            if event.type == pygame.QUIT:
                pygame.display.quit()
                return None
                
            if event.type == pygame.KEYDOWN:
                if event.key == pygame.K_UP:
                    selected_index = (selected_index - 1) % len(com_ports)
                elif event.key == pygame.K_DOWN:
                    selected_index = (selected_index + 1) % len(com_ports)
                elif event.key == pygame.K_RETURN:
                    selected_port = com_ports[selected_index].device
                    pygame.display.quit()
                    return selected_port


if __name__ == "__main__":
    selected_port = create_port_menu()
    if selected_port:
        LiveViewer(selected_port).run()

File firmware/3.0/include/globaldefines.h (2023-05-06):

/*
*
* GLOBAL DEFINES - Global defines, that are used firmware-wide
*
* DIY-Thermocam Firmware
*
* GNU General Public License v3.0
*
* Copyright by Max Ritter
*
* http://www.diy-thermocam.net
* https://github.com/maxritter/diy-thermocam
*
*/

#ifndef GLOBALDEFINES_H
#define GLOBALDEFINES_H

#ifdef __cplusplus
extern "C" {
#endif

/*################# PUBLIC CONSTANTS, VARIABLES & DATA TYPES ##################*/

//Pins
#define pin_button        2
#define pin_lepton_vsync  3
#define pin_touch_irq     5
#define pin_touch_cs      9
#define pin_lcd_dc        10
#define pin_mosi          11
#define pin_miso          12
#define pin_sck           13
#define pin_sda           18
#define pin_scl           19
#define pin_lcd_cs        21
#define pin_lcd_backlight 22
#define pin_bat_measure   23
#define pin_mosi1         26
#define pin_sck1          27
#define pin_lepton_cs     38
#define pin_miso1         39
#define pin_usb_measure   A16

//FLIR Lepton sensor version
#define leptonVersion_2_5_shutter 0 //FLIR Lepton 2.5 Shuttered
#define leptonVersion_3_5_shutter 1 //FLIR Lepton 3.5 Shuttered

//Temperature format
#define tempFormat_celcius    0
#define tempFormat_fahrenheit 1

//Filter type
#define filterType_none     0
#define filterType_gaussian 1
#define filterType_box      2

//Display Min/Max Points
#define minMaxPoints_disabled 0
#define minMaxPoints_min      1
#define minMaxPoints_max      2
#define minMaxPoints_both     3

//Text color
#define textColor_white 0
#define textColor_black 1
#define textColor_red   2
#define textColor_green 3
#define textColor_blue  4

//Screen off time
#define screenOffTime_disabled 0
#define screenOffTime_5min     1
#define screenOffTime_20min    2

//Hot / cold
#define hotColdMode_disabled 0
#define hotColdMode_cold     1
#define hotColdMode_hot      2

//Hot / cold color
#define hotColdColor_white 0
#define hotColdColor_black 1
#define hotColdColor_red   2
#define hotColdColor_green 3
#define hotColdColor_blue  4

//Lepton Gain mode
#define lepton_gain_high 0
#define lepton_gain_low  1

//EEPROM registers
#define eeprom_leptonVersion    100
#define eeprom_tempFormat       101
#define eeprom_colorScheme      102
#define eeprom_convertEnabled   103
#define eeprom_spotEnabled      105
#define eeprom_colorbarEnabled  106
#define eeprom_batteryEnabled   107
#define eeprom_timeEnabled      108
#define eeprom_dateEnabled      109
#define eeprom_storageEnabled   111
#define eeprom_rotationVert     112
#define eeprom_textColor        114
#define eeprom_filterType       115
#define eeprom_minValue1Low     116
#define eeprom_minValue1High    117
#define eeprom_maxValue1Low     118
#define eeprom_maxValue1High    119
#define eeprom_minMax1Set       120
#define eeprom_adjComb1Left     121
#define eeprom_adjComb1Right    122
#define eeprom_adjComb1Up       123
#define eeprom_adjComb1Down     124
#define eeprom_adjComb1Alpha    125
#define eeprom_adjComb1Set      126
#define eeprom_minMaxPoints     127
#define eeprom_screenOffTime    128
#define eeprom_massStorage      129
#define eeprom_hotColdMode      135
#define eeprom_hotColdLevelLow  136
#define eeprom_hotColdLevelHigh 137
#define eeprom_hotColdColor     138
#define eeprom_firstStart       150
#define eeprom_liveHelper       151
#define eeprom_minValue2Low     154
#define eeprom_minValue2High    155
#define eeprom_maxValue2Low     156
#define eeprom_maxValue2High    157
#define eeprom_minMax2Set       158
#define eeprom_minValue3Low     159
#define eeprom_minValue3High    160
#define eeprom_maxValue3Low     161
#define eeprom_maxValue3High    162
#define eeprom_minMax3Set       163
#define eeprom_minMaxPreset     164
#define eeprom_noShutter        169
#define eeprom_batComp			170
#define eeprom_rotationHorizont 171
#define eeprom_minMax1Comp      172 //4 Byte (172-175)
#define eeprom_minMax2Comp      176 //4 Byte (176-179)
#define eeprom_minMax3Comp      180 //4 Byte (180-183)
#define eeprom_lepton_gain      184
#define eeprom_fwVersionLow     250
#define eeprom_fwVersionHigh    251
#define eeprom_setValue         200

//Presets for min/max
#define minMax_temporary  0
#define minMax_preset1    1
#define minMax_preset2    2
#define minMax_preset3    3

//Hardware diagnostic bit codes
#define diag_display 0
#define diag_touch 1
#define diag_sd 2
#define diag_bat 3
#define diag_lepton 4
#define diag_ok 255
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

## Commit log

2017-02-06 Added assembly guide
2017-02-06 Added FW 2.38 and Video Output FW 2.02
    [config.txt]
2017-02-06 Updated assembly guide
2017-02-09 Updated design files
    [Case 2.3_bottom.skp, Case 2.3_bottom.stl, Case 2.3_down.skp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]
2017-02-10 Updated assembly and firmware update guide
2017-02-21 Added support for radiometric Lepton2.5
    [Case 2.3_bottom_radiometric.skp, Case 2.3_bottom_radiometric.stl, Case 2.3_radiometric.skp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]
2017-03-25 Added links for PCB & enclosure
2017-12-05 Allow to override the serial device from the command line
2017-12-09 Live Viewer: Add support for manually setting the calibration data
    This only works from the module interface at the moment.
2018-01-13 Updated enclosure files and readme
    [ArducamV1_NonRadiometric.skp, ArducamV1_NonRadiometric.stl, ArducamV1_Radiometric.skp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]
2018-09-24 Changes to Readme and added 3d printing files (thanks to Llorenç Macià)
    [bottom.ipt, bottom.stl, bottom.stp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]
2018-10-10 Fixed enclosure parts (thanks to Llorenç Macià)
    [bottom.stl, bottom.stp, side1.stl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]
2018-10-25 Enclosure/README.MD updated from https://stackedit.io/
2018-10-25 Updated 3D printing files
    [ArducamV1_NonRadiometric.skp, ArducamV1_NonRadiometric.stl, ArducamV1_Radiometric.skp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]
2019-02-01 Some changes
    [assembly.stl, base.step, base.stl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]
2021-04-14 Adding PCB 3.0
    [PCB 3.0.brd, PCB 3.0.sch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]
2021-04-14 Adding enclosure for V3
    [V3.0.skp]
2021-04-14 Updating PCB BOM image
2021-04-14 Updating BOM
2021-04-28 Cleaned up old stuff and updated Readme for V3 KIT
    [PCB 2.3.brd, PCB 2.3.sch, PCB 3.0.brd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]
2021-05-01 Updates for V3
    [ArducamV1_NonRadiometric.skp, ArducamV1_NonRadiometric.stl, ArducamV1_Radiometric.skp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]
2021-05-16 Small adjustments to the enclosure
    [V3.0.skp]
2023-05-06 Restructured Repository and General Updates
    [PCB 3.0.brd, PCB 3.0.sch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]
2023-05-07 Updated Device Firmware to 3.0.3
2025-02-23 Added Comport Selection Menu and fixed a bug
    [liveviewer.py, main.py]

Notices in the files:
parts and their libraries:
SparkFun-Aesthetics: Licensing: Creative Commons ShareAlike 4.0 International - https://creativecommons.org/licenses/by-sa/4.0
